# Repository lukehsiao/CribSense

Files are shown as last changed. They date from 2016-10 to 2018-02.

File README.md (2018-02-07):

# CribSense: <small>a contactless, video-based baby monitor</small>





# Documentation

Please view our [Documentation Pages](https://lukehsiao.github.io/CribSense) for details and instructions on how to build the project.

## Copyright & License

For license information, view our [license file](LICENSE.md).

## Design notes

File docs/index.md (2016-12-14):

# CribSense Overview

CribSense is a contactless, video-based baby monitor that you can make yourself without breaking the bank.

<a href="img/render-2.jpg">
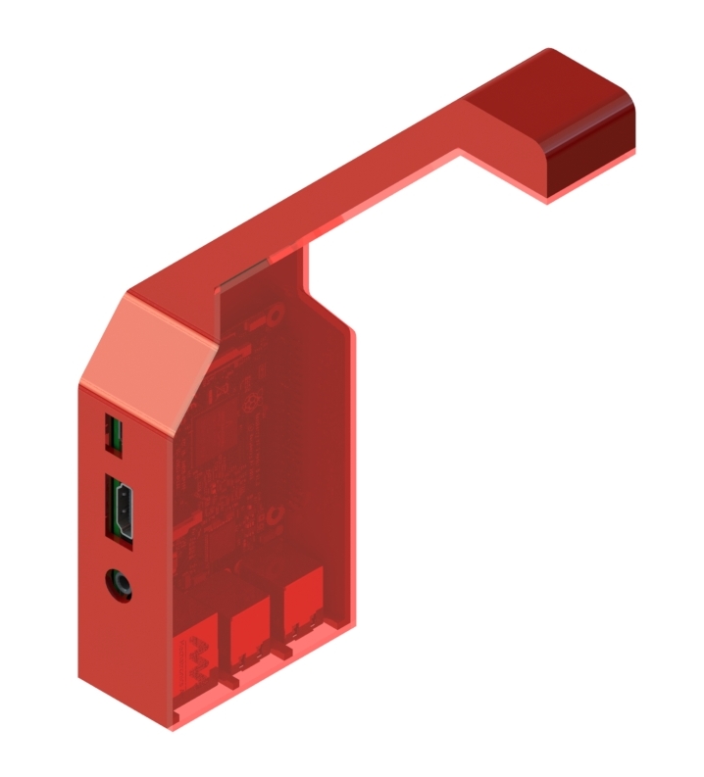
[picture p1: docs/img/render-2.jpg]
render
  
</a>
<a href="img/complete-standing.jpg">
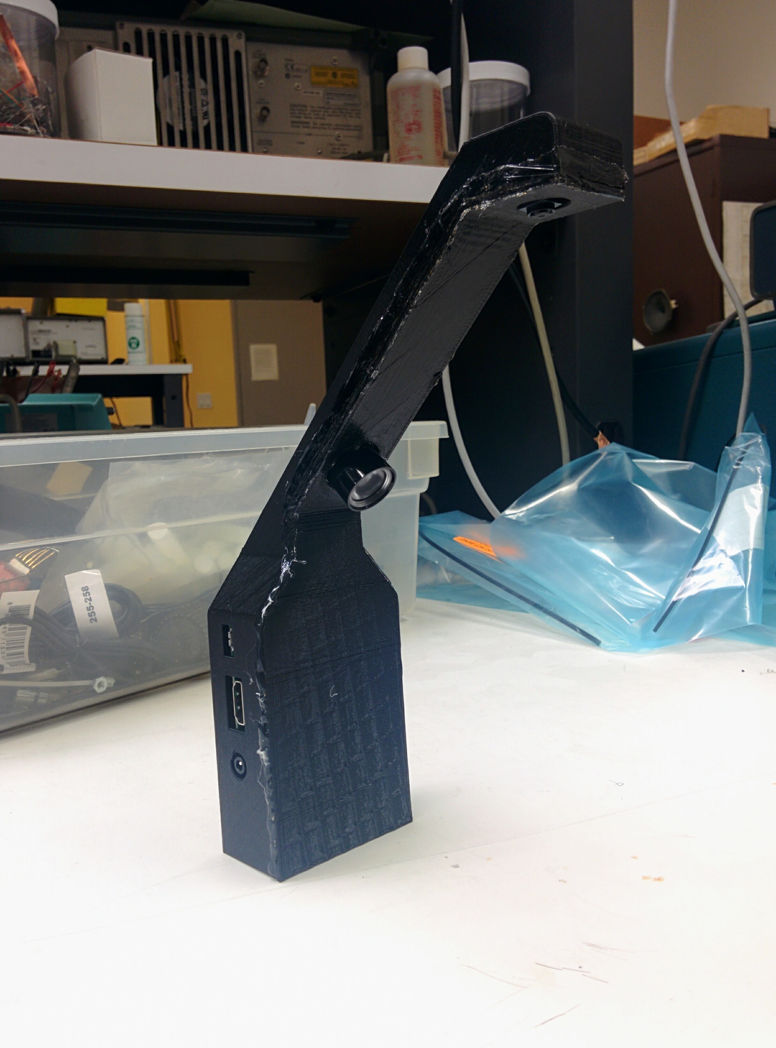
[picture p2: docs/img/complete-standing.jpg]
  
</a>

CribSense is a C++ implementation of the MIT [Video Magnification](http://people.csail.mit.edu/mrub/vidmag/) algorithm that is tuned to run on a Raspberry Pi 3 Model B.
Over a weekend, you can setup your own crib-side baby monitor that raises an alarm if your infant stops moving.
As a bonus, all of the software is free to use for non-commercial purposes and easily extensible.

While we think that CribSense is pretty fun, it is important to remember that this is not actually a certified, foolproof safety device.
That is, CribSense will not work as expected if the system is not calibrated properly.
If the system is not calibrated well or the environment in the video is not conducive to video magnification, you may not be able to use it.
We made this as a fun side project to see how well we could run compute-heavy software, like video magnification, on compute-limited hardware, like a Raspberry Pi.
Any real product would require much more testing than we have done.
If you use this project, take it for what it is: a short exploration of video magnification on a Raspberry Pi.

## Getting Started

CribSense is made up of two parts: the baby monitoring software and some simple hardware.
Find out all you need to know about how to use and recreate your own monitor in the sections below.
You can also view our instructions on [Instructables](http://www.instructables.com/id/CribSense-a-Contactless-Video-based-Baby-Monitor/).

### Software

To install the prerequisites, build the software, or learn more about the software architecture, see the [Software Setup Guide](setup/sw-setup.md).

### Hardware

To learn more about the hardware materials we used, and how we build our setup, check out the [Hardware Setup Guide](setup/hw-setup.md).

## Video Walkthroughs

### Calibrating CribSense

<iframe width="560" height="315" src="https://www.youtube.com/embed/zSiRmgIE3pY?rel=0" frameborder="0" allowfullscreen></iframe>

### CribSense Demonstration

<iframe width="560" height="315" src="https://www.youtube.com/embed/zvy1fXIjGgA?rel=0" frameborder="0" allowfullscreen></iframe>

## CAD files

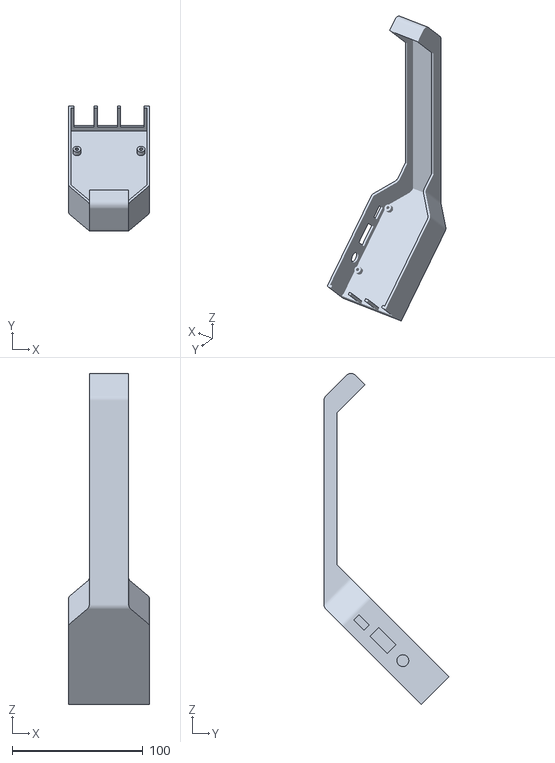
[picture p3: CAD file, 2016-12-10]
chassis/case.stl
62.0 x 95.5 x 252.8

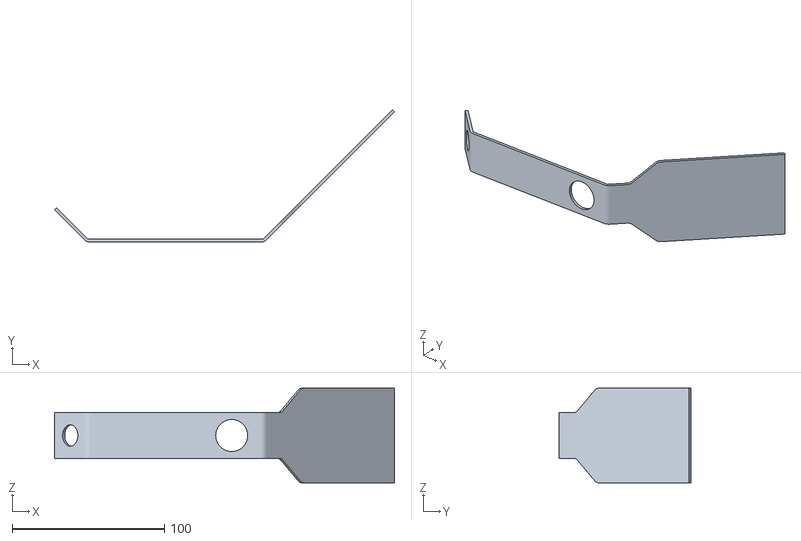
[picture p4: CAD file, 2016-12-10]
chassis/cover.stl
223.0 x 86.9 x 62.0

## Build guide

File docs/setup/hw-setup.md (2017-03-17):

# Hardare Setup Guide

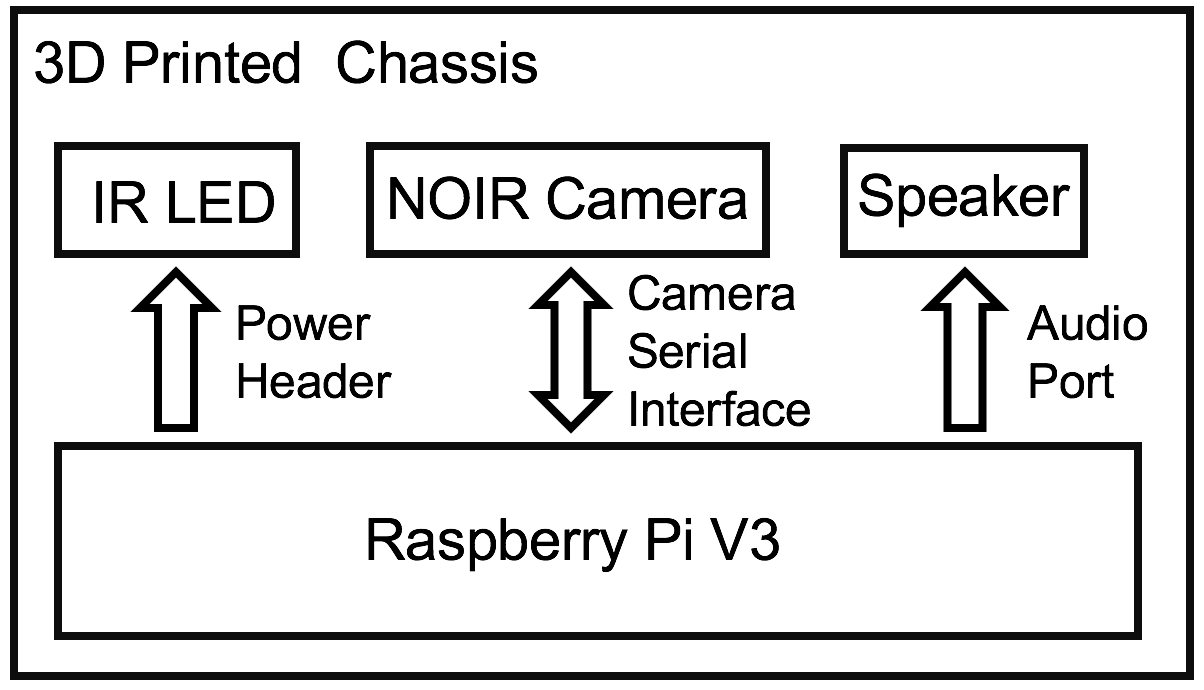
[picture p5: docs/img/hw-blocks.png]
hw-blocks


**Figure: Hardware Block Diagram**

CribSense is relatively easy to construct, and is largely made up of commercially available parts.
As seen in the figure above, there are 5 main hardware components, only 2 of which are custom made.
This page contains the build instructions for CribSense.

## What you'll need

Raspberry Pi + Camera + configuration tools:

-   [Raspberry Pi 3 Model B](https://www.amazon.com/Raspberry-Pi-RASP-PI-3-Model-Motherboard/dp/B01CD5VC92/)
-   [5V 2.5A Micro USB Power Supply](https://www.amazon.com/gp/product/B00MARDJZ4/)
-   [Raspberry Pi NoIR Camera Module V2](https://www.amazon.com/Raspberry-Pi-NoIR-Camera-Module/dp/B01ER2SMHY)
-   [1W IR LED](https://www.amazon.com/DIYmall%C2%AE-Infrared-Adjustable-Resistor-Raspberry/dp/B00NUOO1HQ)
-   [MicroSD Card](https://www.amazon.com/Samsung-Class-Adapter-MB-MP32DA-AM/dp/B00IVPU7KE) (we used a Class 10 16GB card, the faster the card the better)
-   [Flex Cable for Raspberry Pi Camera (12")](https://www.adafruit.com/products/1648)
-   Speakers with 3.5mm input
-   HDMI monitor
-   USB Keyboard
-   USB Mouse
-   \[optional] [Raspberry Pi Heatsink](https://www.amazon.com/LoveRPi-Heatsink-Raspberry-Model-Heatsinks/dp/B018BGRDVS/) (If you're worried about heat, you can stick these onto your Pi.)

IR LED Circuit for low-light operation:

-   [\[3x\] 1N4001 diodes](https://www.adafruit.com/product/755)
-   [1 ohm, 1W resistor](http://www.parts-express.com/10-ohm-1w-flameproof-resistor-10-pcs--003-1)
-   [2x] 12" Wires with pin headers
-   Soldering iron

Chassis:

-   Access to a 3D printer (minimum build volume = 9.9" L x 7.8" W x 5.9" H) to print the chassis
-   Glue (any type of glue will will work, but hot glue is recommended for prototyping)

## Prerequisites

Before you start our step-by-step guide, you should have already installed the latest version of [Raspbian](https://www.raspberrypi.org/downloads/raspbian/) on your SD card and ensured that your Pi is functional and booting.
You'll also need to [enable the camera module](https://www.raspberrypi.org/documentation/configuration/camera.md) before you'll be able to interface with the camera.

## Build Instructions

### Swap NoIR Camera Cable

The 6" cable that comes with the camera is too short.
Swap the short one (6") with the longer one (12").
To do this, you can follow [this guide from ModMyPi](https://www.modmypi.com/blog/how-to-replace-the-raspberry-pi-camera-cable).
To summarize, there is a push/pull tab on the back of the NoIR camera, just like the one found on the Pi itself:

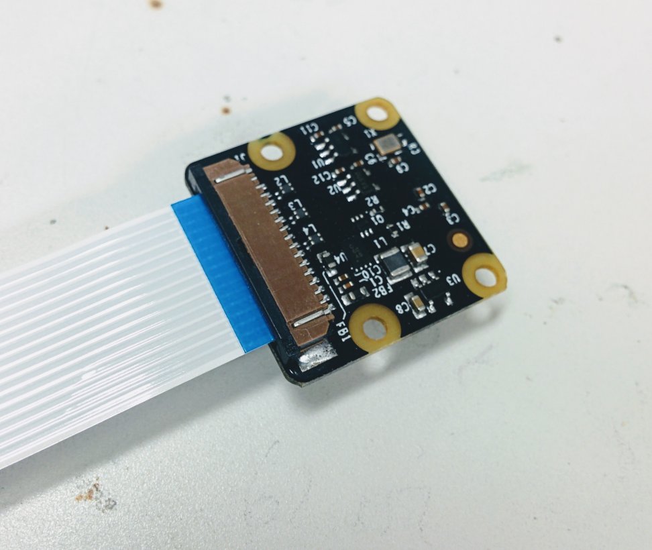
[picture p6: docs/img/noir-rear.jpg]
noir-rear


Simply pull the black plastic tab out, remove the short cable, replace it with the long cable (making sure that the blue plastic strip is facing up still as shown in the picture), and push the tab back in to secure it.

### 3D Printed Chassis

<a href="../../img/render-2.jpg">
  Render 2
</a>

Using our chassis is optional, though recommended to prevent young children from touching exposed electronic circuitry.
Every crib is different, so our chassis does not include include a mounting bracket.
Several mounting options could include:

-   [Cable Ties](https://www.amazon.com/Miady-Pieces-Self-Locking-Nylon-Inches/dp/B01M0IL0GO/)
-   [3M Dual Lock](https://www.amazon.com/3M-Reclosable-Fastener-SJ3560-Clear/dp/B00PX22H42/)
-   [Velcro](https://www.amazon.com/VELCRO-Brand-Industrial-Strength-Black/dp/B00006RSP1/)
-   Tape

If you have access to a MakerBot Replicator (5th Generation), you can simply download the `.makerbot` files for the [case](https://github.com/lukehsiao/CribSense/raw/master/chassis/case.makerbot) and [cover](https://github.com/lukehsiao/CribSense/raw/master/chassis/cover.makerbot) onto your MakerBot Replicator and print.
It takes about 6 hours to print the case and 3 hours to print the cover.
If you are using a different type of 3D printer, please keep reading.

As mentioned above, a minimum build volume of 9.9" (L) x 7.8" (W) x 5.9" (H) is required to print CribSense.
If you do not have access to a 3D printer with this build volume, you can use an online 3D printing service (such as [Shapeways](http://www.shapeways.com/) or [Sculpteo](https://www.sculpteo.com/)) to print CribSense.
The minimum print resolution is 0.015".
If you are using a [fused filament fabrication](https://en.wikipedia.org/wiki/Fused_filament_fabrication) type 3D printer, this means that your nozzle diameter needs to be 0.015" or smaller.
Printers with lower print resolutions (larger nozzle diameters) may work, but the Raspberry Pi might not fit into the chassis.
We recommend PLA (polylactic acid) as the preferred printing material.
Other plastics may work, but the Raspberry Pi may not fit in the case if the thermal expansion coefficient of the chosen plastic is larger than that of PLA.
If your 3D printer has a heated build plate, turn off the heater before proceeding.

Orienting the model on your printer's build plate is critical for a successful print.
These models were carefully designed so they do not need to be printed with support material, thus saving plastic and improving print quality.
Before proceeding, download the 3D files for the [case](https://github.com/lukehsiao/CribSense/blob/master/chassis/case.stl) and [cover](https://github.com/lukehsiao/CribSense/blob/master/chassis/cover.stl).
When printing these models, the neck of CribSense must lay flat on the build plate.
This ensures that all overhang angles on the models do not exceed 45 degrees, thus eliminating the requirement for support material.
For instructions on orientating 3D models in the build volume of your printer, please refer to the instruction manual that comes with your 3D printer.
Examples for the build orientation of the case and cover are shown below.

Case:

<a href="../../img/print-case-iso.png">
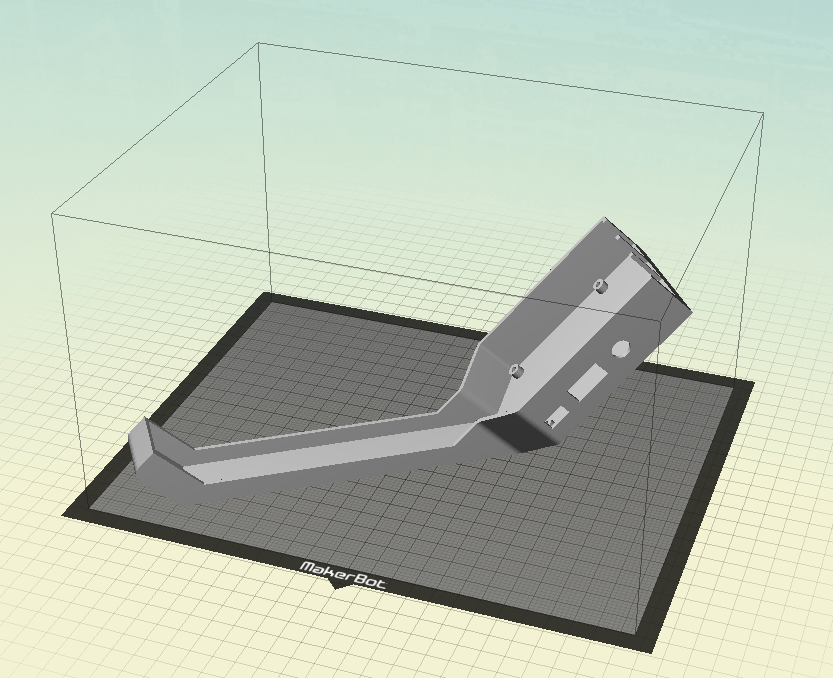
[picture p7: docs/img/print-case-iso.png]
Case (Isometric View)
  
</a>
<a href="../../img/print-case-top.png">
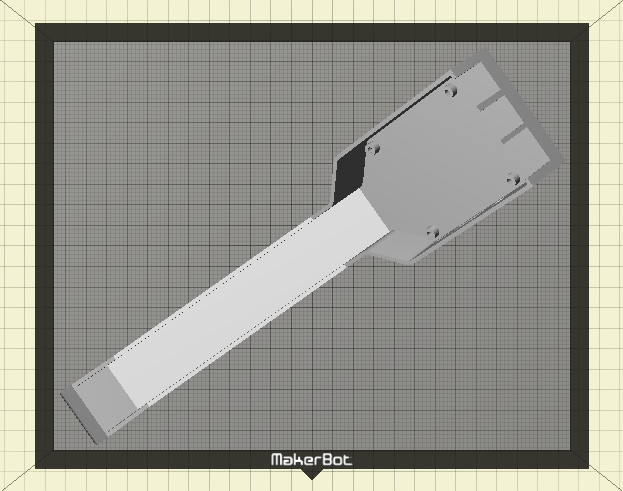
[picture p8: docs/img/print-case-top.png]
Case (Top View)
  
</a>

Cover:

<a href="../../img/print-cover-iso.png">
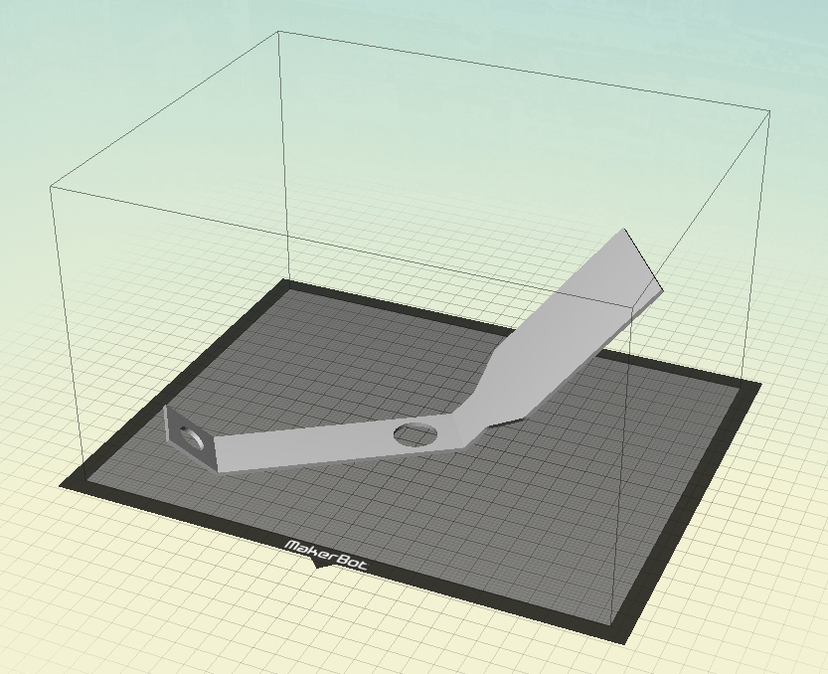
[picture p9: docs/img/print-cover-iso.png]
Cover (Isometric View)
  
</a>
<a href="../../img/print-cover-top.png">
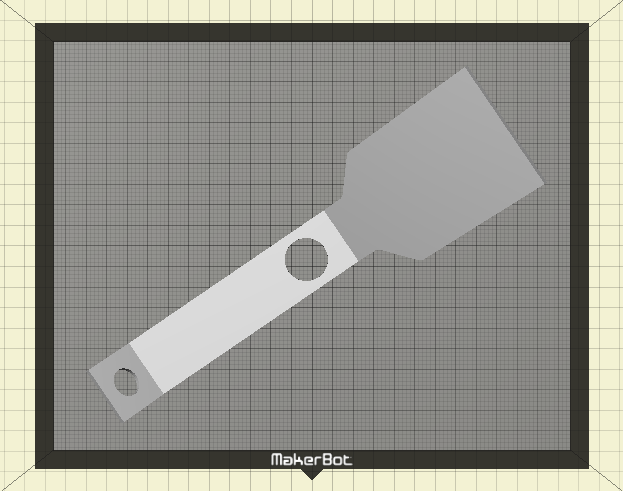
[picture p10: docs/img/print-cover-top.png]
Cover (Top View)
  
</a>

In addition to putting the neck of CribSense flat against the build plate, you may notice that the models are rotated around the vertical axis.
This may be necessary to fit the model inside the build volume of your 3D printer.
This rotation is optional if the length of your build volume is long enough to accommodate CribSense.

### IR LED Circuit

In order to provide adequate lighting at night, we use an IR LED, which is not visible to the human eye but visible to the NoIR camera.
The IR LED does not consume a lot of power compared to the Raspberry Pi, so we leave the IR LED on for the sake of simplicity.

To power the LED from the GPIO header pins on the Pi, we construct the circuit in the figure below.

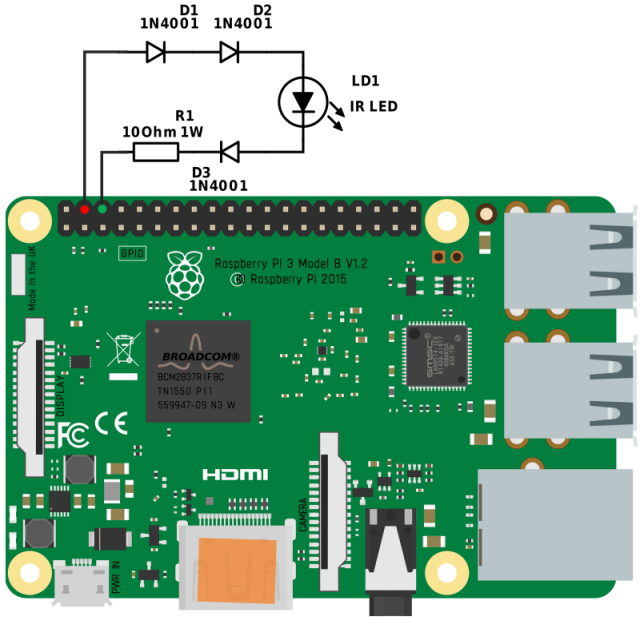
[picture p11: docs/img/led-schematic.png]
led

**Figure: LED Schematic**

In earlier versions of the Pi, the maximum output current of these pins was [50mA](http://pinout.xyz/pinout/pin1_3v3_power).
The Raspberry Pi B+ increased this to 500mA.
However, for simplicity and backwards compatibility, we use the 5V power pins, which can supply up to [1.5A](http://pinout.xyz/pinout/pin2_5v_power).
The forward voltage of the IR LED is about 1.7~1.9V according to our measurements.
Even though the IR LED has a maximum current of 500mA, we decided to reduce the current to around 200mA to reduce heat and overall power consumption.
Experimental results also show that the IR LED is bright enough with 200 mA of input current.
To bridge the gap between 5V and 1.9V, we decided to use three 1N4001 diodes and a 1 Ohm resistor in series with the IR LED.
The voltage drop over the wire, diodes and resistor is about 0.2V, 0.9V (for each one) and 0.2V, respectively.
Thus, the voltage over the IR LED is `5V - 0.2V - (3 * 0.9V) - 0.2V = 1.9V`.
The heat dissipation over each LED is 0.18W, and is 0.2W over the resistor, all well within the maximum ratings.

The circuit should looking something like this:

<a href="../../img/ir-led-zoom.jpg">
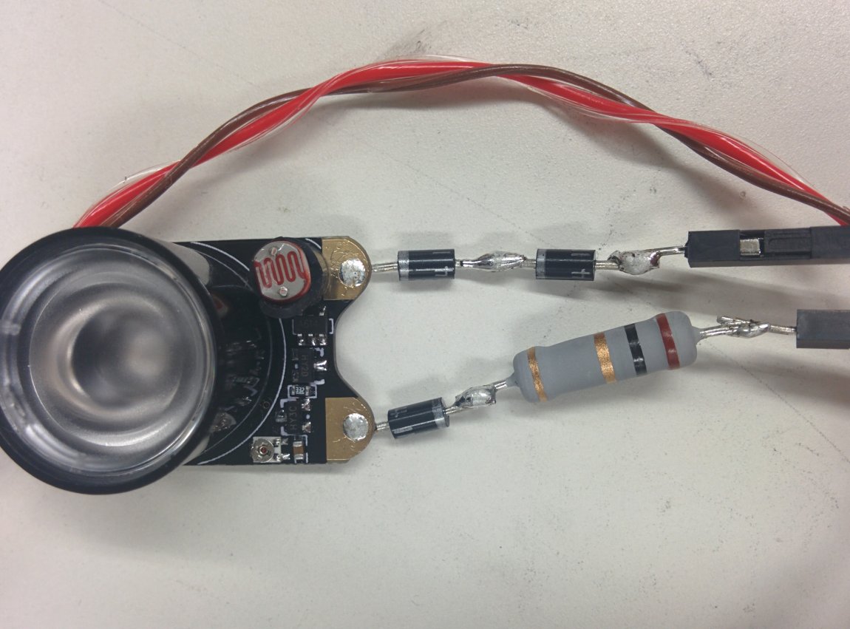
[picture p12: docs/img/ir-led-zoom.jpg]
zoom
  
</a>
<a href="../../img/ir-led-full.jpg">
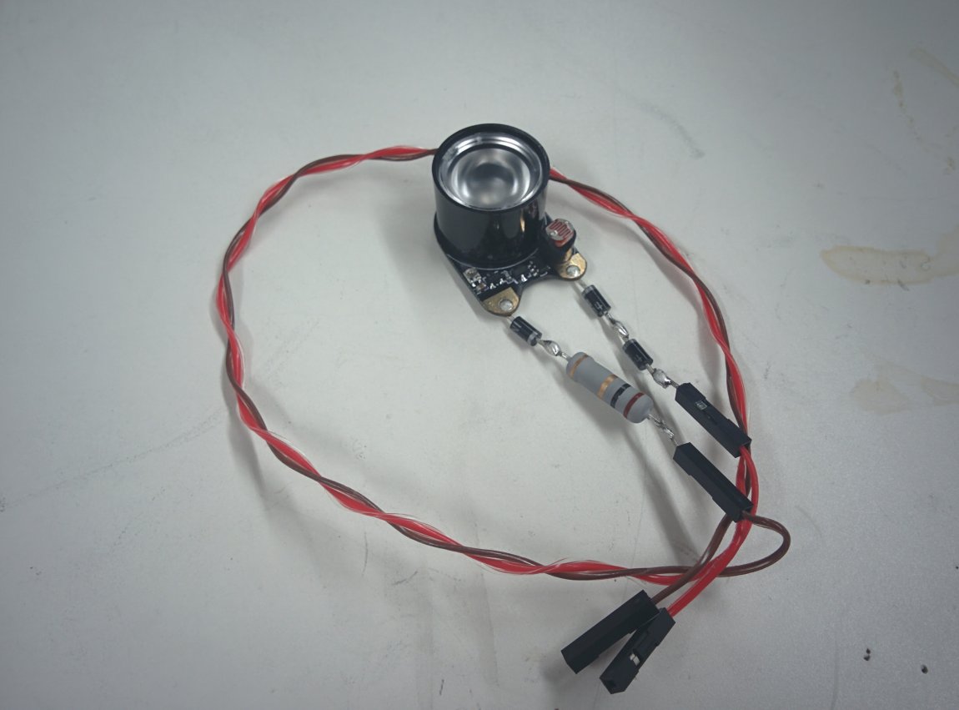
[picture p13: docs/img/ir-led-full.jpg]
full
  
</a>

But, we're not done yet!
In order to get a better fit in the 3D printed chassis, we want to have the IR LED lens protrude from our chassis and have the PCB board flush with the hole.
The small photodiode in the bottom right will get in the way.
To remedy this, we desolder it and flip it to the opposite side of the board like this:

<a href="../../img/photodiode-side.jpg">
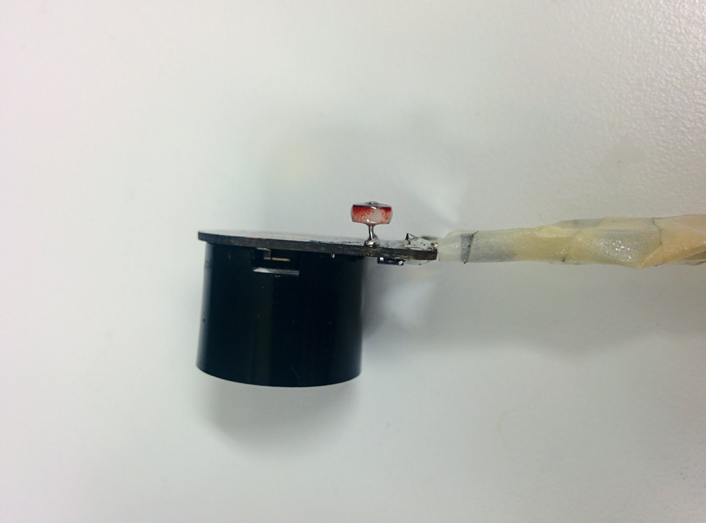
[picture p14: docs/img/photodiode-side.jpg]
side
  
</a>
<a href="../../img/photodiode-front.jpg">
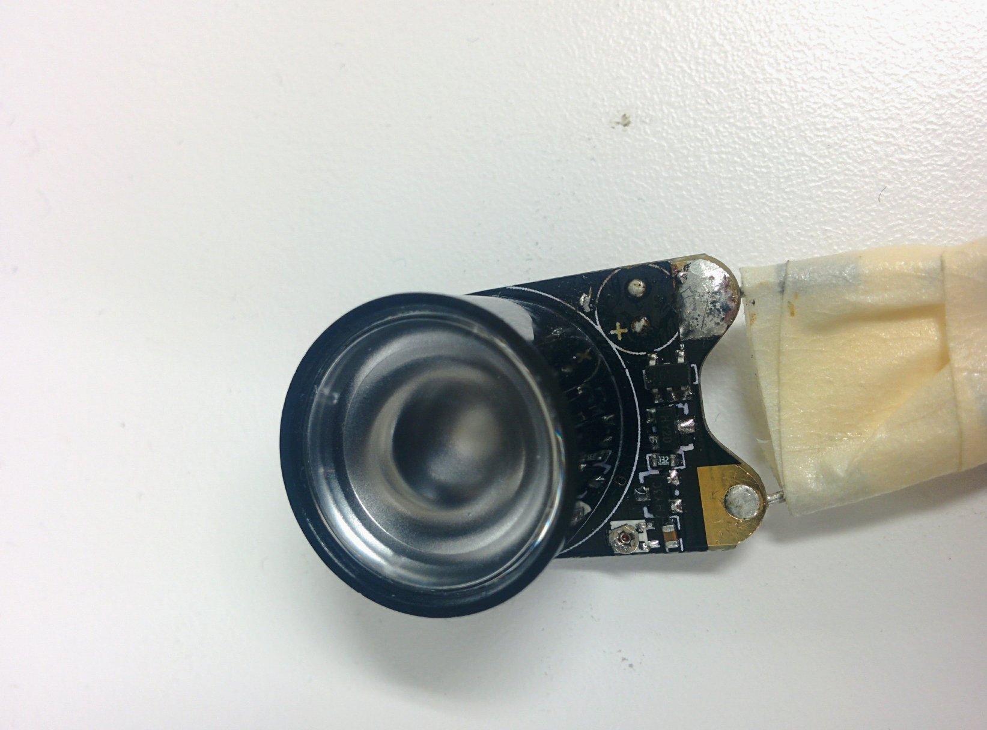
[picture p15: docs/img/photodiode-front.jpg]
front
  
</a>

The photodiode is not needed since we want the LED to always be on.
Simply switching it to the opposite side leaves the original LED circuit unchanged.

### Assembly: Bring it all together

Once you have all the hardware ready, you can begin assembly.
Any glue can be used in this process, but we recommend hot glue for two main reasons.
Hot glue drys quickly, so you do not need to wait a long time for the glue to dry.
In addition, hot glue is removable if you make a mistake.
To remove dried hot glue, soak the hot glue in in rubbing (isopropyl) alcohol.
We recommend 90% concentration or higher, but 70% concentration will still work.
Soaking the dried hot glue in isopropyl alcohol will weaken the bond between the glue and underlying surface, allowing you to peel the glue off cleanly.
When soaking the glue in isopropyl alcohol, the Raspberry Pi should be powered off and unplugged.
Be sure to let everything dry before reapplying hot glue and booting the Raspberry Pi.

The assembly instructions below assume that you are using hot glue.
If you are using a different type of glue, the assembly instructions still apply, though the drying times may differ.
Throughout this process, make sure that the glue is dry before moving on to the next step.
Throughout the build, check to make sure that all the ports can still be accessed through the holes in the CribSense chassis.
Click any of the pictures below for higher resolution images.

-   Insert the Raspberry Pi into the chassis. Once it is in place, be sure that all of the ports can still be accessed (e.g. you can plug in power power).

<a href="../../img/pi-chassis.jpg">
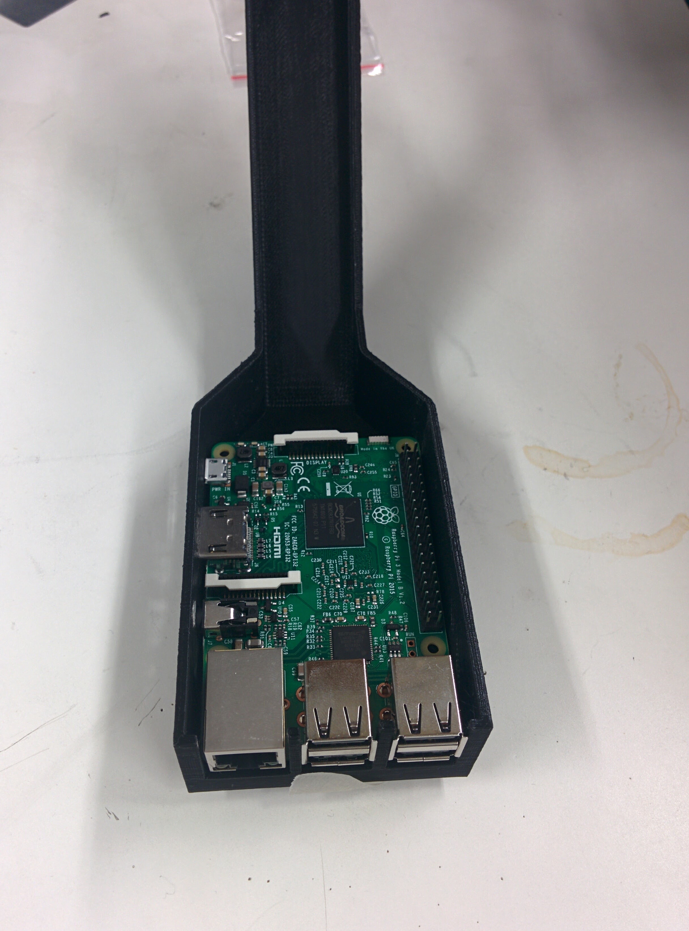
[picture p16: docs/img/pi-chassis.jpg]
  
</a>

-   Next, use hot glue to tack the Pi into place and attach the camera to the Pi. There are screw holes as well if you prefer to use those.

<a href="../../img/pi-glued.jpg">
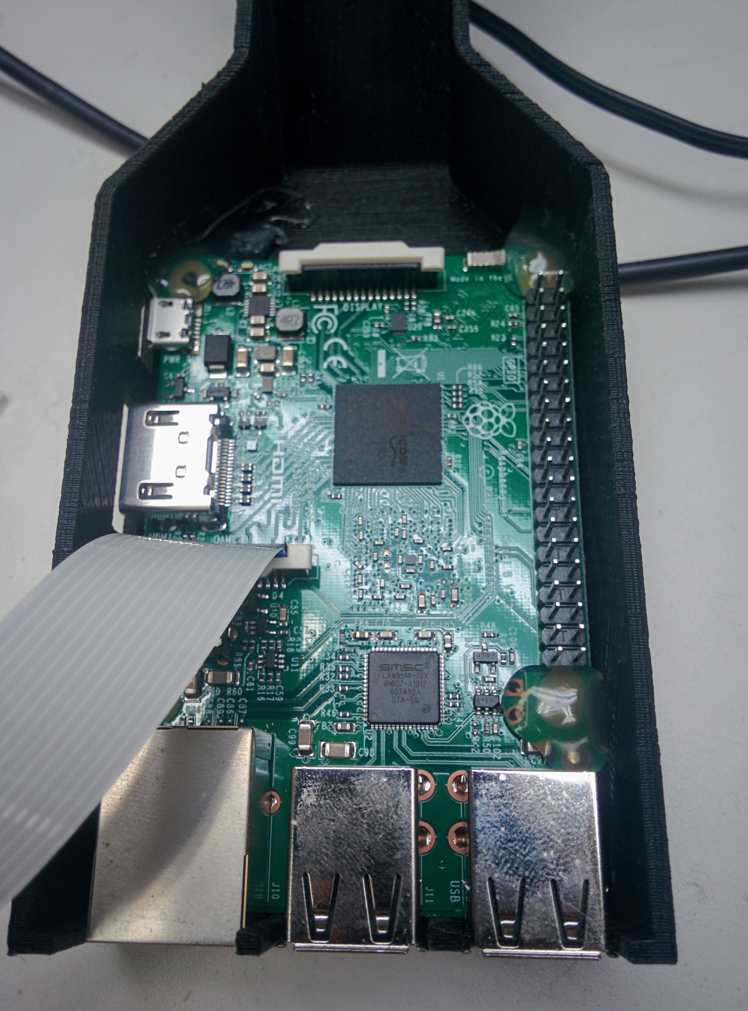
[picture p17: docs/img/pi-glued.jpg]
  
</a>

-   Glue the LED and camera to the front cover.

<a href="../../img/chassis-front.jpg">
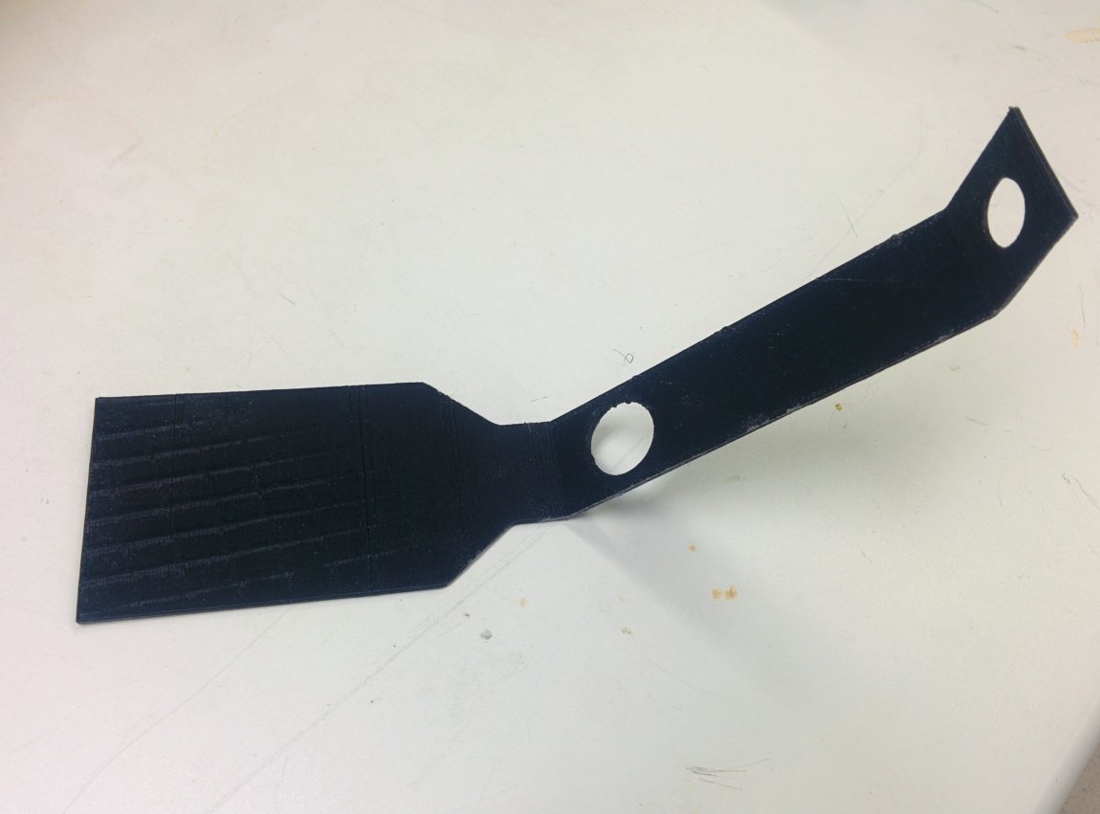
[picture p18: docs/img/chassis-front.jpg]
front
  
</a>

-   First, glue the NoIR camera to the camera hole. Be sure that the camera is snug and lined up with the chassis. Do not use too much glue; otherwise, you will not be able to fit the camera into the main case. Be sure to power on the Pi and take a look at the camera (`raspistill -v`, for example) to make sure that it is angled well and has a good field of view. If it is not, remove the hot glue and reposition it.

<a href="../../img/noir-glued.jpg">
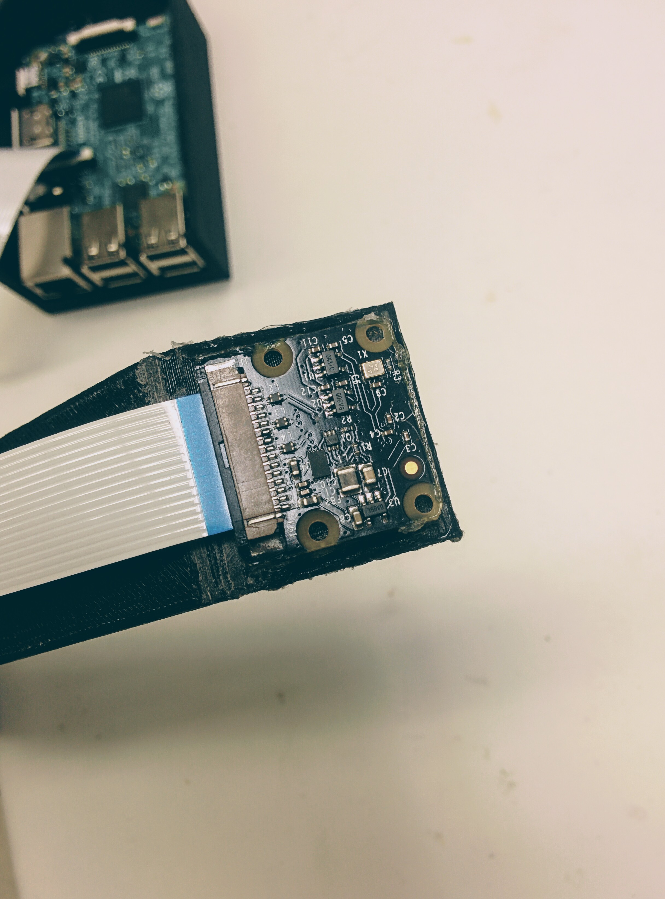
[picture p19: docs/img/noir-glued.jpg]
  
</a>

-   Next, glue the IR LED to the hole on the neck of the cover. It's at a 45 degree angle to side light the crib, which results in more shadows in low-light situations. This adds more contrast to the image, making it easier to detect motion.

<a href="../../img/ir-led-glued-zoom.jpg">
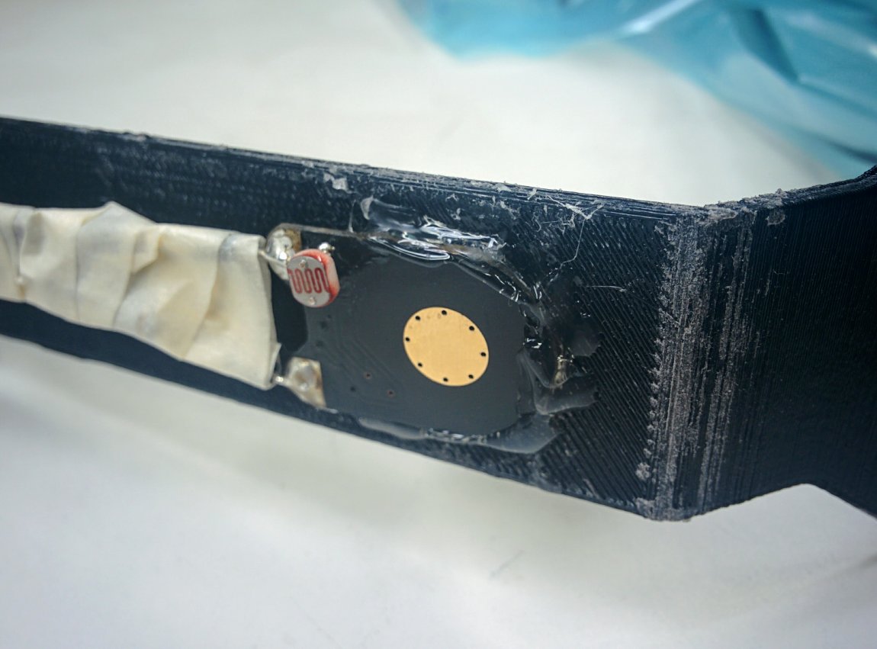
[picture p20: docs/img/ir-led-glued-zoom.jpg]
  
</a>

-   With both of them glued to the neck, it should look like this:

<a href="../../img/ir-led-glued-front.jpg">
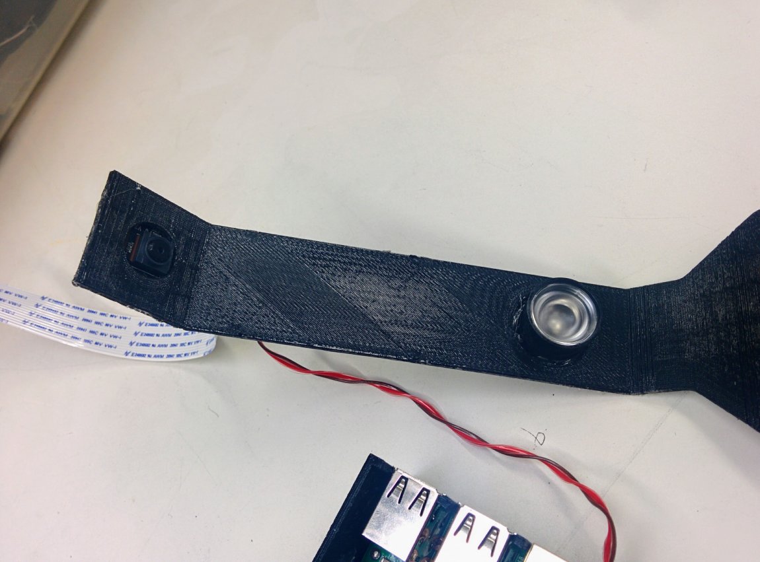
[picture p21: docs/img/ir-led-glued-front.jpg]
front
  
</a>
<a href="../../img/ir-led-glued-rear.jpg">
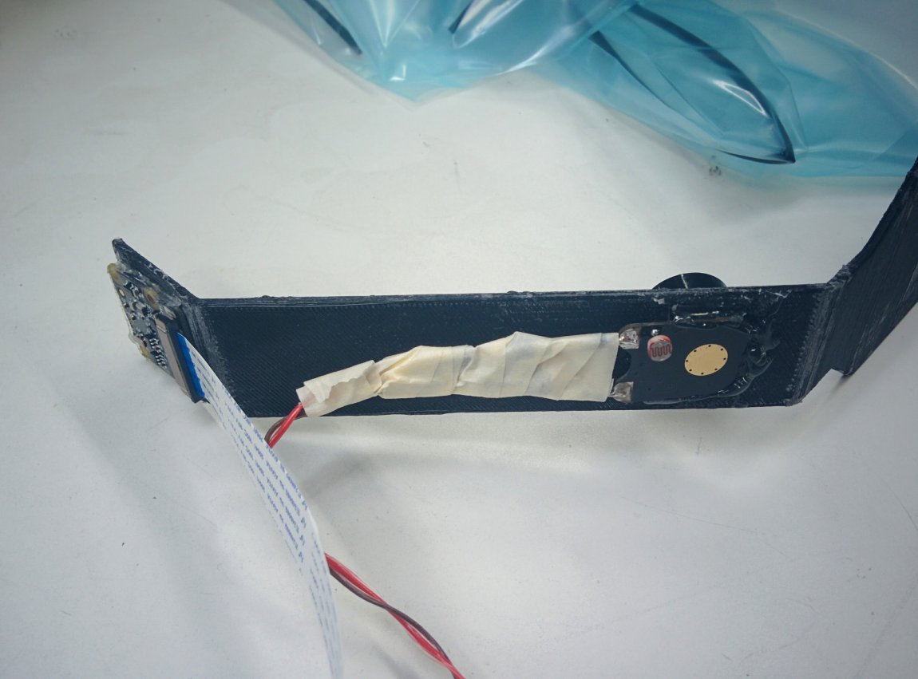
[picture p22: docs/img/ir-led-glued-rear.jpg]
  
</a>

-   Attach the IR LED wires to the Raspberry Pi's GPIO pins as shown in the LED Schematic figure.
-   Pack the cables into the chassis in a way that does not crease or strain them. We ended up folding the cable accordion style because our camera flex cable was too long.

<a href="../../img/cable-packing.jpg">
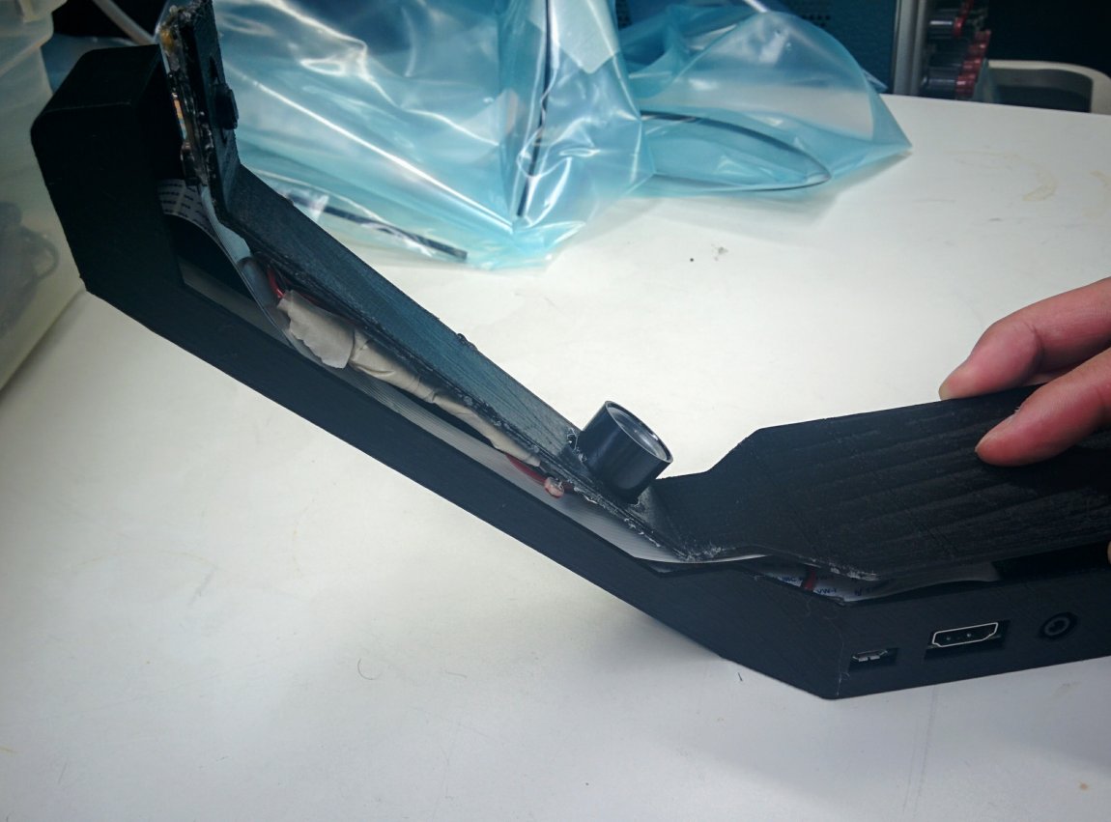
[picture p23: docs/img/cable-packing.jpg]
  
</a>

-   With everything tucked in, hot glue around the edges where the two pieces meet, sealing them in place.

<a href="../../img/complete-standing.jpg">
  front
</a>
<a href="../../img/complete-ports.jpg">
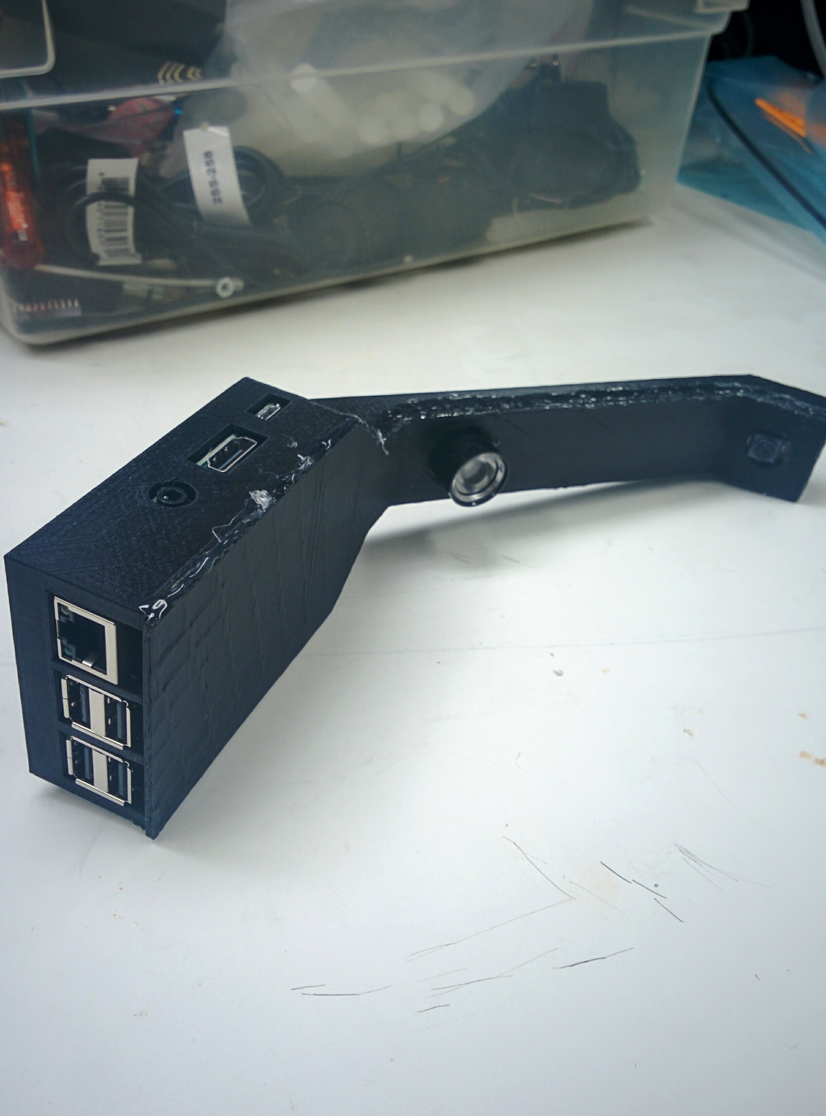
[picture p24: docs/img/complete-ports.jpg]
  
</a>

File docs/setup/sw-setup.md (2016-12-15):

# Software Setup Guide

This is the step-by-step guide on building the CribSense software on Raspbian/Ubuntu.

## Prerequisites

This software depends on [autoconf](https://www.gnu.org/software/autoconf/autoconf.html), [libtool](https://www.gnu.org/software/libtool/), [OpenCV](http://opencv.org/) and [libcanberra](https://en.wikipedia.org/wiki/Libcanberra). Install these by running

```sh
sudo apt-get install git build-essential libtool autoconf libopencv-dev libcanberra-dev
```

Next you need to set to camera driver to autoload by adding `bcm2835-v4l2` to `/etc/modules-load.d/modules.conf`.
Your `modules.conf` should look like this:

```sh
# /etc/modules: kernel modules to load at boot time.
#
# This file contains the names of kernel modules that should be loaded
# at boot time, one per line. Lines beginning with "#" are ignored.

i2c-dev
bcm2835-v4l2
```
Once you've added the line and saved the file, **reboot your Raspberry Pi**.
This is the driver used by CribSense to directly pull frames from the NoIR Camera.

## Build

To build the software, navigate to the root of the repository directory and run

```sh
./autogen.sh --prefix=/usr --sysconfdir=/etc --disable-debug
make
sudo make install
sudo systemctl daemon-reload
```
## Usage

To start the program in the background:

```sh
sudo systemctl start cribsense
```

To run it in the foreground:

```sh
cribsense --config /etc/cribsense/config.ini
```

To start the program automatically at every boot:

```sh
sudo systemctl enable cribsense
```

To stop cribsense from automatically running at boot:

```sh
sudo systemctl disable cribsense
```

Note that when `cribsense` is started using `systemctl`, the config parameters are already sent and are stored in `/etc/systemd/system/cribsense.service`

Once you have installed the software and have it configured well for your setting, you will no longer need the keyboard/mouse/monitor. Now, you can set your CribSense to autorun at every boot as shown above.

Now, all you'll need to do is plug in speakers, attach the CribSense to your previously tested spot on the side of your crib, and plug it in. The software will automatically run after a few moments, and will begin tracking motion. When you're done, well, we don't have an elegant way for you to turn off the Pi yet. But, you can just unplug the speakers and leave it running (and be sure to set the infant in the crib for a couple minutes before plugging them back in). Directly unplugging the Pi may corrupt your SD card.

Remember that if the environment changes, you'll probably need to reconfigure. You'll want to disable the autorun using the command above, and go through the calibration steps on the [Configuration Page](./config.md).

If something doesn't seem to be working, you can checkout our [Troubleshooting Page](./troubleshooting.md)

Tip: If everything is set up, you can [make a backup of your Raspberry Pi SD Card](https://www.raspberrypi.org/documentation/linux/filesystem/backup.md) for easy restoration if something goes wrong.

## Software Configuration

CribSense customizable through a simple INI configuration file.
After running `make install`, the configuration file is located at:

```sh
sudo nano /etc/cribsense/config.ini
```

and it will look like this
```ini
[io]                  ; I/O configuration
; input = vid/noir_cam/lowres_10fps_orange_2min.h264   ; Input file to use
input_fps = 15          ; fps of input (40 max, 15 recommended if using camera)
full_fps = 4.5          ; fps at which full frames can be processed
crop_fps = 15           ; fps at which cropped frames can be processed
camera = 0              ; Camera to use
width = 640             ; Width of the input video
height = 480            ; Height of the input video
time_to_alarm = 10      ; How many seconds to wait with no motion before alarm.

[cropping]            ; Adaptive Cropping Settings
crop = true                 ; Whether or not to crop
frames_to_settle = 10       ; # frames to wait after reset before processing
roi_update_interval = 800   ; # frames between recalculating ROI
roi_window = 50             ; # frames to monitor before selecting ROI

[motion]              ; Motion Detection Settings
erode_dim = 4           ; dimension of the erode kernel
dilate_dim = 60         ; dimension of the dilate kernel
diff_threshold = 8      ; abs difference needed before recognizing change
duration = 1            ; # frames to maintain motion before flagging true
pixel_threshold = 5     ; # pixels that must be different to flag as motion
show_diff = false       ; display the diff between 3 frames

[magnification]       ; Video Magnification Settings
amplify = 25                ; The % amplification desired
low-cutoff = 0.5            ; The low frequency of the bandpass.
high-cutoff = 1.0           ; The high frequency of the bandpass.
threshold = 50              ; The phase threshold as % of pi.
show_magnification = false  ; Show the output frames of each magnification

[debug]
print_times = false ; Print analysis times

```

View the full configuration details on the [Configuration Page](./config.md)

## Software Architecture Details
The CribSense software is the heart and soul of this project.
The rest is mainly a fun opportunity to use a 3D printer and do some soldering.
We saw some of the great demos of [video magnification](http://people.csail.mit.edu/mrub/vidmag/) from MIT, and wanted to try and run a similar algorithm on a Raspberry Pi.
 This required about 10x speedup from the great work of [tbl3rd on his C++ implementation](https://github.com/tbl3rd/Pyramids) of video magnification in order to run in real-time on the Pi.
 The optimizations needed guided our design of the software.

The software for processing a video stream is implemented as a state machine that cycles as shown below.
There are currently six states that manage all of our processing steps.
Our state machine logic is called each time a new frame is read from the camera.

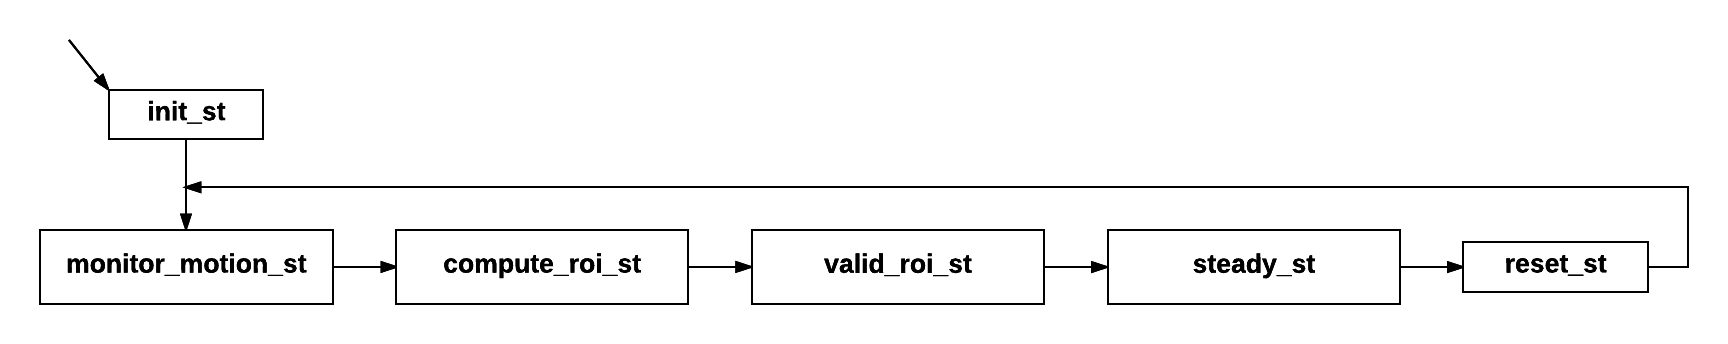
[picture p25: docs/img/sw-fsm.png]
fsm


### Initialization

When the video stream first turns on, it is common to have a flash of white or black pixels that looks like a lot of motion is happening.
This state simply initializes the video magnification and motion detection code, and skips a few of the first frames before jumping into monitoring motion.

### Monitoring Motion

In this state, the full 640 x 480 frame is magnified, and uses an image differential algorithm from Collins et al. to calculate the motion pixels between frames.
The output of this algorithm is a black and white image where white pixels indicate pixels that have changed.
These black and white images are then bitwise ORed together for several frames to accumulate the motion seen over the period of time.

### Computing a Region of Interest

With the accumulated black and white frame representing the motion seen over several frames, the image is eroded slightly to eliminate noise, then significantly dilated to highlight the areas with the most motion.
Dilation is necessary to merge discrete points into continuous regions of motion.
Because of the large dilation, it is then easy to find the largest contour in the black and white image, which represents the main source of motion, and draw a bounding box around the contour.
It is in this portion of code that we can set bounds on the size of the crop.

### Steady State

This is where our software spends most of its time.
In this state, the software is operating on cropped frames.
Video magnification is performed and a measure of the movement seen in the frame is calculated.
In this state, we are able to process at a fast enough rate to catch up with any delay caused during the processing of full frames, and keep up with our 10fps video stream.

### Periodic Reset

Because the baby may move occasionally, we periodically reset the video magnification and cropping so that we have full-resolution frames available to repeat the process of monitoring motion and finding a new region of interest.
All of these timing parameters are easily configurable.

## Technical Challenges

### Speed

When we started this project, our C++ implementation could magnify video at a rate of 394,000 pixels per second on the Raspberry Pi 3.
For reference, this meant our code could only process a 640 x 480 video stream at a rate of approximately 1.3 frames per second.  
Optimizing our code to handle the real-time goal was our primary objective and challenge, since we needed a 10x speed-up to handle at least 10 frames per second.
Now, we are able to process over 1,200,000 pixels per second, and use additional cropping to process a 10 fps video stream in real time.

We used three main optimizations increase performance by 10x: (1) multithreading, (2) adaptive cropping, and (3) compiler optimization. Each optimization is explained in more detail below.

#### Multithreading (~3x)

One intuitive and high-value optimization was to process sections of each video frame in parallel.
To do so, we divide each frame vertically, such that each section's height is one-third of the original frame.
Then, each section is magnified as if it was its own video stream.
The resulting magnified frames are then joined together to form a full-resolution frame before evaluating the frame for motion.
This optimization alone brought our processing rate to 938,000 pixels per second (roughly a 3x improvement).
Three of the Raspberry Pi's four cores are dedicated to video magnification, while the 4th core handles control flow and motion processing.

#### Adaptive Cropping (~3x)

While multithreading sought to increase the number of pixels we could process each second, adaptive cropping sought to decrease the number of pixels we needed to process.
We rely on two main assumptions for this optimization.
First, the camera captures the entire crib in its field of view and the baby is the only source of movement in the frame.
Second, the camera is placed such that movement is discernible, and the region of interest is not larger than one-third of the frame.
With these assumptions, we are able to periodically monitor a full frame to determine where the motion is occurring, then crop down the stream to only contain the relevant motion.
By reducing the number of pixels that we process in our steady state, and amortizing the cost of monitoring a few full-resolution frames, we are able to increase the number of frames we can handle each second by about 3x.

#### Compiler Optimizations (~1.2x)

Finally, in order to reach our goal of over 10x speedup, we were able to make some code optimizations and utilize additional compiler flags.
In particular, we make use of the -O3 optimization level, and we force the compiler to generate vector instructions with `-ftree-vectorize` and `-mfpu=crypto-neon-fp-armv8`.
Additionally, we were required to add the `-funsafe-math-optimization` flag to enable the vector float generation, because NEON instructions are not IEEE compliant and gcc would not generate them otherwise.

We found two major challenges in enabling compiler optimization.
The first was to expose the operations to the compiler.
The most expensive part of transformation happens in two all-pixel loops, but previously each operation in the loop was implemented with an opencv call that would run the operation over all pixels.
We rewrote the code to pull out the loop and avoid intermediate copies.
On an x86-64 machine, this is already an improvement, because of larger caches and the fact that the compiler always issues at least SSE2 vector instructions.
In contrast, the switch from vector instruction enabled opencv to straight C++ code resulted in worse performance on the Pi.

We recovered this performance drop by adding the compiler flags, but we encountered toolchain problems.
The Pi 3 has an ARM Cortex A53 processor, which is an A-class 64-bit ARMv8 with NEON and crypto extensions, but it runs a 32-bit OS compiled for ARMv7.
We found first that compiling with `-march=native` exposes a known but yet unfixed GCC bug.
Compiling with `-march=armv8` appears to work, but generates ABI incompatible binaries when linked with an ARMv7 libstdc++, leading to stack corruption.
On the other hand, leaving the default of -march=armv7 and forcing just the FPU to generate NEON appears to work, looking at the assembly.
We also added `-mtune=cortex-a53` to achieve better instruction scheduling and better counts for loop unrolling (which is enabled at -O3), but we suspect it has no effect because the version of GCC we use (4.9.2, provided by Raspbian) does not recognize it.

### Profiling

In order to isolate further optimization spots, we employed profiling to identify where the code is spending most of the time.
In doing so, we also encountered toolchain problems, as `valgrind` is unable to emulate the NEON vector instructions and crashes.
We therefore turned to `gprof`, but we found its timing somewhat unreliable, despite the `-fno-inline` switch (function call counts on the other hand are precise but not quite useful).
Finally, we tried `perf`, which uses the HW performance counters and gives us instruction level timings, but we found that it is very precise inside the transformation code, and has zero data outside, because it sees no sample of the other code.
Overall, profiling suggests that 96% of the time is spent in the transformation and 2% in motion detection, with the rest being threading and locking overhead, and accessing the camera.

### Timing

Overall, our algorithm is able to process a full 640x480 frame in 220 to 240 ms, while after cropping our algorithm runs in the worst case (where the crop is approximately 320x320) at about 70 ms per frame.
This allows us to maintain a steady 10 fps goal.

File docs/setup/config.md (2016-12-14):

# Configuration

Configuration of CribSense uses a file which is usually located in `/etc/cribsense/config.ini`.

The format is that of INI files: each line is a configuration value, and directives are grouped in section introduced by square brackets. Comments are delimited with `;` to the end of the line.

## Input/Output

The `[io]` section of the file configures the input to CribSense.
You should not need to modify this section, as it is already calibrated to work on the Raspberry Pi.

The `input` directive specifies that the magnifier should look for a video file instead of real-time camera input, while `camera` directive chooses the camera device to use (eg. `camera = 0` means to use `/dev/video0` as input).
File input exists as a demo or debugging feature only.

If you change the input, you must also specify the fps parameters to match the input.
For file input, there is only one fps setting, because frames are never dropped, while for camera input, to reduce latency you must specify the frame per second at full frame size and at cropped frame size (roughly 3x the full frame size fps).
The latter values depend on the speed of the CPU on which cribsense run.
Note that when using an input file that is less than 15 fps, `crop_fps` should be set to the input file's fps value in order to ensure the bandpass frequencies are calculated correctly.

`time_to_alarm` determines the number of system-time seconds to wait after cribsense stops seeing motion before playing an alarm sound through the audio port.

## Cropping

The `[cropping]` section controls the adaptive motion-based cropping, which focuses the magnification process on a smaller Region of Interest (ROI) where the most motion is occurring, reducing the CPU load.

The different parameters affect the latency of detection, as they control the number of "slow" frames (fully uncropped).
Optimal values for the parameters depend on the target CPU.
If you're running on a different device than the Pi, and it's sufficiently powerful, you can also disable cropping altogether.

The default configuration will update the crop approximately every minute.

## Motion & Magnification

The `[motion]` and `[magnification]` sections control the motion detection and video magnification algorithm respectively.

These parameters depend on the setting in which the cribsense is deployed, such as lighting condition and contrast on the baby.
In general, you should not need to change the magnification setting, as it is tuned to detect normal breathing rates.

Calibration may be needed for `erode_dim` and `dilate_dim`, which are used to determine where to crop the video, as well as `diff_threshold` and `pixel_threshold` which determine the thresholds used judge the magnitude of change in pixels and the number of pixels of motion are needed before being classified as motion rather than noise.

Specifically, `diff_threshold` specifies the amount of change a grayscale pixel (value between 0 and 255) will need to change before being marked as changed.
For example, if `diff_threshold` is 30, the difference between a pixels has to be equal to or more than 30 to be marked changed.
The higher this threshold, the more the pixels needs to be different to be marked.

`pixel_threshold` defines a hard cut of in the number of pixels that need to be marked as changed before outputting motion values.
This effectively sets the cutoff for noise when determining whether or not an infant is breathing.
For example, if `pixel_threshold` is set to 100, the algorithm must see more than 100 pixels of change before registering any motion as seen. It will report no motion if that threshold is not crossed.

`erode_dim` specifies the dimension of the kernel to use in an [OpenCV erode operation](http://docs.opencv.org/2.4/doc/tutorials/imgproc/erosion_dilatation/erosion_dilatation.html).
This is used to minimize the changed pixels.
That is, pixels that are isolated will be removed, but when large groups of pixels are changed, they will remain.
`dilate_dim` is the opposite, it takes a pixels and expands it.
These two parameters are used when detecting the region of the frame that the infant is located in.
First, the pixel differences are calculated, then, a small erosion is applied to eliminate noise and a large dilation is applied to broadly mark the areas of motion.

`low-cuttoff` and `high-cutoff` define the range of the bandpass filter used during magnification.
Specifically, video magnification will try to magnify motion that occurs within this frequency range, and ignore motion outside this range.
We've tuned this to be able to capture breathing rats in general, but you may need to tweak this during calibration.

See the section on calibration for more information.

## Debugging features

The `show_diff` flag in `[motion]` will show a window where the areas where motion is detected in the frame are highlighted in white.
The `show_magnification` flag in `[magnification]` controls a window that shows the output of just video magnification (which should look like the camera feed, in black and white, with enlarged motion).
You can use these two flags to show the result of your changes to the motion and magnification parameters.

Finally, the `print_times` in the `[debug]` section controls printing of frame times in the standard output, which you can use to calibrate the FPS and latency settings when running on a device different than the Raspberry Pi.

These features must be left to off when cribsense is started through systemd (automatically on boot or with `systemctl start`). They are only useful if you run cribsense manually.

## Calibrating the Motion & Magnification algorithm

Calibration of the algorithm is an iterative effort, with no right or wrong answer.
We encourage you to experiment with various values, combining them with the debugging features, to find the combination of parameters most suitable to your environment.

As a guideline, increasing the `amplification` and the `phase_threshold` values increases the amount of magnification applied to the input video.
You should change these values until you clearly see the movement from your baby breathing, and no significant artifact in other areas of the video.
If you experience artifacts, reducing the `phase_threshold` while keeping the same `amplification` might help.
You can view the effects of these parameters by setting `show_magnification` to `true`.

As for the motion detection parameters, the main driver is the amount of noise.
When detecting regions of motion to crop to, `erode_dim` and `dilate_dim` are used to size the dimensions of the OpenCV kernels used to [erode and dilate](http://docs.opencv.org/2.4/doc/tutorials/imgproc/erosion_dilatation/erosion_dilatation.html) motion so that noise is first eroded away, then the remaining motion signal is significantly dilated to make the regions of motion obvious.
These parameters may also need to be tuned if your crib is in a very high-contrast setting.
In general, you will need a higher `erode_dim` for high contrast settings, and a lower `erode_dim` for low contrast.

If you run with `show_diff = true` and you notice that too much of the input video is white, or some completely unrelated part of the video is detected as motion (e.g. a flickering lamp), you'll want to increase the `erode_dim` until only the part of the video corresponding to your breathing baby is the largest section of white.
The top figure shows an example where the erode dimension is too low for the amount of motion in the frame, while the bottom one shows a correctly calibrated frame.

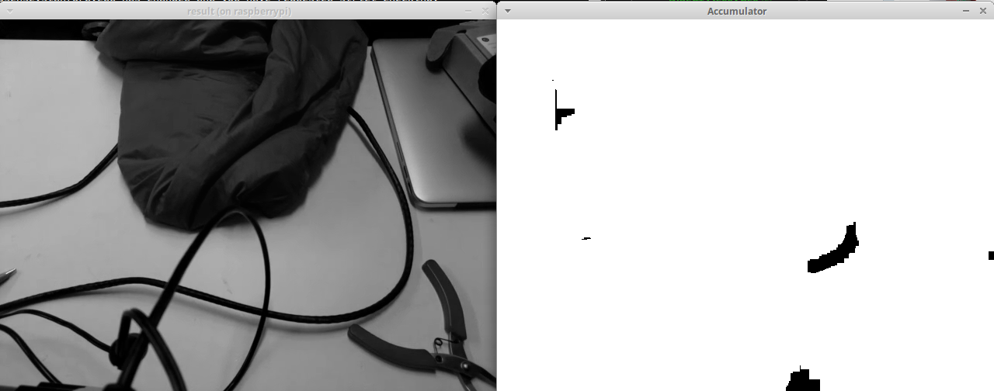
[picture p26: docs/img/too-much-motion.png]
too-much


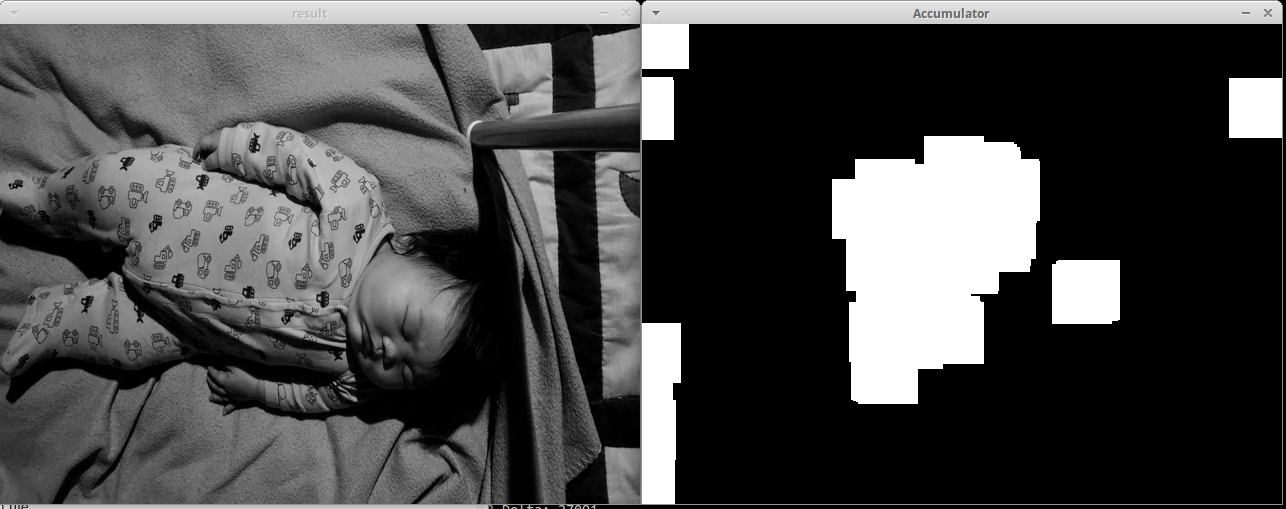
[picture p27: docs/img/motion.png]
motion


Once this has been calibrated, you'll want to make sure that the `pixel_threshold` is set so that motion is only reported when you expect, and not constantly (which means you need to cut out the noise).
Ideally, you'll see output like this in your terminal:

```sh
[info] Pixel Movement: 0	 [info] Motion Estimate: 1.219812 Hz
[info] Pixel Movement: 0	 [info] Motion Estimate: 1.219812 Hz
[info] Pixel Movement: 0	 [info] Motion Estimate: 1.219812 Hz
[info] Pixel Movement: 0	 [info] Motion Estimate: 1.219812 Hz
[info] Pixel Movement: 44	 [info] Motion Estimate: 1.219812 Hz
[info] Pixel Movement: 0	 [info] Motion Estimate: 1.219812 Hz
[info] Pixel Movement: 161	 [info] Motion Estimate: 1.219812 Hz
[info] Pixel Movement: 121	 [info] Motion Estimate: 0.841416 Hz
[info] Pixel Movement: 0	 [info] Motion Estimate: 0.841416 Hz
[info] Pixel Movement: 86	 [info] Motion Estimate: 0.841416 Hz
[info] Pixel Movement: 0	 [info] Motion Estimate: 0.841416 Hz
[info] Pixel Movement: 0	 [info] Motion Estimate: 0.841416 Hz
[info] Pixel Movement: 0	 [info] Motion Estimate: 0.841416 Hz
[info] Pixel Movement: 0	 [info] Motion Estimate: 0.841416 Hz
[info] Pixel Movement: 0	 [info] Motion Estimate: 0.841416 Hz
[info] Pixel Movement: 0	 [info] Motion Estimate: 0.841416 Hz
[info] Pixel Movement: 0	 [info] Motion Estimate: 0.841416 Hz
[info] Pixel Movement: 0	 [info] Motion Estimate: 0.841416 Hz
[info] Pixel Movement: 0	 [info] Motion Estimate: 0.841416 Hz
[info] Pixel Movement: 0	 [info] Motion Estimate: 0.841416 Hz
[info] Pixel Movement: 0	 [info] Motion Estimate: 0.841416 Hz
[info] Pixel Movement: 0	 [info] Motion Estimate: 0.841416 Hz
[info] Pixel Movement: 0	 [info] Motion Estimate: 0.841416 Hz
[info] Pixel Movement: 0	 [info] Motion Estimate: 0.841416 Hz
[info] Pixel Movement: 0	 [info] Motion Estimate: 0.841416 Hz
[info] Pixel Movement: 97	 [info] Motion Estimate: 0.841416 Hz
[info] Pixel Movement: 74	 [info] Motion Estimate: 0.839298 Hz
[info] Pixel Movement: 0	 [info] Motion Estimate: 0.839298 Hz
[info] Pixel Movement: 60	 [info] Motion Estimate: 0.839298 Hz
[info] Pixel Movement: 0	 [info] Motion Estimate: 0.839298 Hz
[info] Pixel Movement: 0	 [info] Motion Estimate: 0.839298 Hz
[info] Pixel Movement: 0	 [info] Motion Estimate: 0.839298 Hz
[info] Pixel Movement: 0	 [info] Motion Estimate: 0.839298 Hz
[info] Pixel Movement: 48	 [info] Motion Estimate: 0.839298 Hz
[info] Pixel Movement: 38	 [info] Motion Estimate: 0.839298 Hz
[info] Pixel Movement: 29	 [info] Motion Estimate: 0.839298 Hz
[info] Pixel Movement: 28	 [info] Motion Estimate: 0.839298 Hz
[info] Pixel Movement: 22	 [info] Motion Estimate: 0.839298 Hz
[info] Pixel Movement: 0	 [info] Motion Estimate: 0.839298 Hz
[info] Pixel Movement: 0	 [info] Motion Estimate: 0.839298 Hz
[info] Pixel Movement: 0	 [info] Motion Estimate: 0.839298 Hz
[info] Pixel Movement: 0	 [info] Motion Estimate: 0.839298 Hz
```
Where there is a clear periodic pattern corresponding to the motion.

If your output looks more like this:

```
[info] Pixel Movement: 921	 [info] Motion Estimate: 1.352046 Hz
[info] Pixel Movement: 736	 [info] Motion Estimate: 1.352046 Hz
[info] Pixel Movement: 666	 [info] Motion Estimate: 1.352046 Hz
[info] Pixel Movement: 663	 [info] Motion Estimate: 1.352046 Hz
[info] Pixel Movement: 1196	 [info] Motion Estimate: 1.352046 Hz
[info] Pixel Movement: 1235	 [info] Motion Estimate: 1.352046 Hz
[info] Pixel Movement: 1187	 [info] Motion Estimate: 1.456389 Hz
[info] Pixel Movement: 1115	 [info] Motion Estimate: 1.456389 Hz
[info] Pixel Movement: 959	 [info] Motion Estimate: 1.456389 Hz
[info] Pixel Movement: 744	 [info] Motion Estimate: 1.456389 Hz
[info] Pixel Movement: 611	 [info] Motion Estimate: 1.456389 Hz
[info] Pixel Movement: 468	 [info] Motion Estimate: 1.456389 Hz
[info] Pixel Movement: 371	 [info] Motion Estimate: 1.456389 Hz
[info] Pixel Movement: 307	 [info] Motion Estimate: 1.456389 Hz
[info] Pixel Movement: 270	 [info] Motion Estimate: 1.456389 Hz
[info] Pixel Movement: 234	 [info] Motion Estimate: 1.456389 Hz
[info] Pixel Movement: 197	 [info] Motion Estimate: 1.456389 Hz
[info] Pixel Movement: 179	 [info] Motion Estimate: 1.456389 Hz
[info] Pixel Movement: 164	 [info] Motion Estimate: 1.456389 Hz
[info] Pixel Movement: 239	 [info] Motion Estimate: 1.456389 Hz
[info] Pixel Movement: 733	 [info] Motion Estimate: 1.456389 Hz
[info] Pixel Movement: 686	 [info] Motion Estimate: 1.229389 Hz
[info] Pixel Movement: 667	 [info] Motion Estimate: 1.229389 Hz
[info] Pixel Movement: 607	 [info] Motion Estimate: 1.229389 Hz
[info] Pixel Movement: 544	 [info] Motion Estimate: 1.229389 Hz
[info] Pixel Movement: 499	 [info] Motion Estimate: 1.229389 Hz
[info] Pixel Movement: 434	 [info] Motion Estimate: 1.229389 Hz
[info] Pixel Movement: 396	 [info] Motion Estimate: 1.229389 Hz
[info] Pixel Movement: 375	 [info] Motion Estimate: 1.229389 Hz
[info] Pixel Movement: 389	 [info] Motion Estimate: 1.229389 Hz
[info] Pixel Movement: 305	 [info] Motion Estimate: 1.312346 Hz
[info] Pixel Movement: 269	 [info] Motion Estimate: 1.312346 Hz
[info] Pixel Movement: 1382	 [info] Motion Estimate: 1.312346 Hz
[info] Pixel Movement: 1086	 [info] Motion Estimate: 1.312346 Hz
[info] Pixel Movement: 1049	 [info] Motion Estimate: 1.312346 Hz
[info] Pixel Movement: 811	 [info] Motion Estimate: 1.312346 Hz
[info] Pixel Movement: 601	 [info] Motion Estimate: 1.312346 Hz
[info] Pixel Movement: 456	 [info] Motion Estimate: 1.312346 Hz
```
Then you'll need to adjust `pixel_threshold` and `diff_threshold` until just peaks are seen, and pixel movement is 0 otherwise.

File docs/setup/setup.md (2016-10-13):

# Setup Guide

This is the step-by-step guide on building the cribsense software on Ubuntu.

## Prerequisites
This software depends on Qt5 and OpenCV. Install these by running

```sh
sudo apt-get install qtbase5-dev qtdeclarative5-dev libqt5webkit5-dev libsqlite3-dev
sudo apt-get install qt5-default qttools5-dev-tools
```

To install [OpenCV](http://docs.opencv.org/2.4/doc/tutorials/introduction/linux_install/linux_install.html), run:
```
sudo apt-get install build-essential
sudo apt-get install cmake git libgtk2.0-dev pkg-config libavcodec-dev libavformat-dev libswscale-dev
sudo apt-get install libopencv-dev
```

## Build
To build the software, navigate to the root of the directory and run

```sh
qmake src/Magnifier.pro
make
```

To execute the program:

```
./Magnifier
```

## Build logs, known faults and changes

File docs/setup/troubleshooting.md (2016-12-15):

# Troubleshooting

Here are some troubleshooting tips we've gathered while making CribSense.

### No alarm is playing

-   Are your speakers working?
-   Can you play other sounds from the Pi outside of the CribSense alarm?
-   Is your Pi trying to play audio through HDMI rather than the audio port? Check the [Raspberry Pi Audio Configuration](https://www.raspberrypi.org/documentation/configuration/audio-config.md) page to make sure that you have selected the right output.
-   Is CribSense detecting motion? Check with `journalctl -f` to see if CribSense is running in the background. If it is, perhaps you need to [calibrate CribSense](./config.md)

### IR LED is not working

- Can you see a faint red color when you look at the IR LED? A faint red ring should be visible when the LED is on.
- Check the polarity of the connections. If +5V and GND are reversed, it will not work. 
- Connect the LED to a power supply with a 5V/0.5A voltage/current limit. Normally, it should consume 0.2A at 5V. If it does not, your LED may be malfunctioning.

### CribSense is detecting motion even though there isn't an infant

-   Have you properly [configured CribSense](./config.md)?
-   Remember, CribSense is just looking for changes in pixel values
    -   Is there a moving shadow within the frame?
    -   Is there flickering or changing lighting?
    -   Is CribSense mounted to a stable surface (e.g. something that won't shake if people are walking by it)?
    -   Is there any other sources of movement in the frame (mirrors catching reflections, etc)?

### CribSense is NOT detecting motion even though there is motion

-   Have you properly [configured CribSense](./config.md)?
-   Is there anything in the way of the camera?
-   Are you able to connect to the camera from the Raspberry Pi at all? Check by running `raspistill -v` in a terminal to open the camera on the Pi for a few seconds.
-   If you look at `sudo systemctl status cribsense`, is it actually running?
-   Is your infant under a blanket that is "tented" up so that it is not making contact with the child? If there are significant air gaps between the blanket and the child, the blanket may mask the motion.
-   Can you see the motion if you amplify the video more?
-   Can you see the motion if you tune the low and high frequency cutoffs?
-   If this is happening in low-light only, did you make sure your calibration works in low-light?

### CribSense doesn't build

-   Did you [install all of the dependencies](./sw-setup.md)?

### I can't run `cribsense` from the commandline

-   Did you accidentally mistype anything when you ran `./autogen.sh --prefix=/usr --sysconfdir=/etc --disable-debug` during your software build?
-   Is `cribsense` present in `/usr/bin/`?

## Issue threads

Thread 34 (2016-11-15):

Document circuitry needed to hook the IR LED to the Pi.

lukehsiao, 2016-11-15:
We'll want to know what parts were used and how they are hooked up, plus some pictures. Whatever information is necessary for a non-technical person to reproduce it from the instructable.

lukehsiao, 2016-12-06:
Added to the docs.

Closed 2016-12-06.

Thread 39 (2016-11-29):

Add source files & documentation for 3D printing chassis to repo

lukehsiao, 2016-11-29:
We can add a `chassis/` folder to the root and have the model files there. Ideally, people can just come to this repo for all the files needed to recreate the project.

lukehsiao, 2016-12-09:
Also need to add any new render images to `docs/img/` and fill out the documentation on both GitHub and Instructable on the print process/design decisions and assembly. I'll work on some of the assembly instructions.

lukehsiao, 2016-12-11:
closed in fe477f14f3a42ecf77f10743f504c29f35c59572

Closed 2016-12-11.

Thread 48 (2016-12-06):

Resolder photodiode to the rear of the LED

lukehsiao, 2016-12-06:
Pan, can you desolder and photodiode that is on the front of the IR LED and solder it to the back?

lukehsiao, 2016-12-08:
Thanks @lghupan ! Closing this issue.

Closed 2016-12-08.

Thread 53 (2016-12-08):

Feedback for documentation/instructable

lukehsiao, 2016-12-08:
Here's the feedback we got.

From Phil:

- [x] adding a bit more detail on how things work and why. E.g., explain what each of the three libraries use and why you chose them (well, maybe not autoconf).
- [x] Please include a troubleshooting section: if X doesn’t work, what should someone look at? Is there a consistent problem you run into? Think not just about telling someone how to do it if everything goes perfectly, but also how to recover from failures.
- [x] Please explain what it’s actually doing and include a video of it operating. (#49)
- [x] You’re in some ways suggesting a safety device, and so need to explain its limitations/issues. You don’t want someone to actually use this to protect their baby then come after you when it fails. I.e., say that you embarked on this to figure out whether it was possible, and a real product would need more QA, etc.
- [x] Show what a full setup looks like. How do you install the camera? What considerations are there for its placement/orientation? Should they worry about HDR/light?

From Shane:

- [x] A picture of the camera cable replacement process would be helpful
- [x] Not strictly necessary, but it would be good to communicate that the chassis itself is an 'optional' part of the build if they have other means of constructing it. Separating the materials list into "chassis-related" and "electronics/essential" would be helpful in that regard
- [x] Providing a simple 'hello world' version of the configuration file (inline if possible) would help people immediately understand the syntax and the relevant parameters without the need to read every word of your Software Configuration document.
- [x] Alongside your (really cool) picture of the CAD model, it would be great to see a picture of the finished build on the first page. This will give your project a much more tangible and 'do-able' feel. When people see a CAD model, they think 'fancy', but when they see a picture of a real project, right away they can better envision themselves using or building it.
- [x] Step 4 was a great example of explaining design decisions with technical detail. It would be good to have a little bit more of a technical overview of the software design in this fashion.
- [x] With your software license, good job listing the relevant dependency licenses in your README, but don't forget to explicitly license the CribSense code that you guys wrote as well.
- [x] Finally, make sure you have a summary or step that focuses on the nominal usage, eg. once they've done all the necessary setup and calibration.

lukehsiao, 2016-12-08:
I'm checking these things off as I add them to the github repo docs. Once everything is in the GitHub repo, we can uncheck them as we make sure they're in the instructable.

lukehsiao, 2016-12-09:
Ok, I think I've gotten basically all of these points in both our GitHub docs and the Instructable. The only holes remaining are the Chassis docs. If you all could take a look and do some editing, that would be great.

lukehsiao, 2016-12-11:
William has added the chassis info. All that is needed now is a final sync between github docs and the instructable.

lukehsiao, 2016-12-14:
Shane wants us to make a **Troubleshooting** step to the instructable.

Closed 2016-12-15.

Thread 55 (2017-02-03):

Virtual Camera Source

dtynski, 2017-02-03:
I'm running a virtual camera source instead of the camera in your tutorial.  When I specify that camera (which I can view via VLC so I know the virtual device is working), I get a "invalid argument error from Cribsense. Any idea how to troubleshoot?

gcampax, 2017-02-03:
Try running it in strace (strace -e trace=ioctl cribsense) to see what IOCTL is failing. It's likely that we're passing some parameter value (eg picture format) that is valid for the Pi driver but not for your camera.

Closed 2017-03-14.

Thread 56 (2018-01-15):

Viewing the video stream

tomforsyth90, 2018-01-15:
This is exactly what I was looking to implement into my baby monitor. I've got it working so it is currently streaming the video via gstreamer but wanted to know if there was a way to use this also to monitor movement and breathing? If I download CribSense on a new sd card it runs fine but if I run it on the sd card i'm using for my baby monitor video stream it doesn't work and fails after starting the batch processing.. any suggestions how I can get this to work? Also is there a way to visualise the pixel movement and motion estimate to reflect breathing rate? Thanks

lukehsiao, 2018-01-15:
>If I download CribSense on a new sd card it runs fine but if I run it on the sd card i'm using for my baby monitor video stream it doesn't work and fails after starting the batch processing.. any suggestions how I can get this to work?

This one would be hard to debug without a lot of details. I'm not sure what might be causing this.

>Also is there a way to visualise the pixel movement and motion estimate to reflect breathing rate?

It is possible to show the diff frames similar to the one you see during configuration
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

but in our implementation, rendering these added too much overhead and the Pi couldn't keep up. Adding any other visual indicators would have to be very lightweight. We do have some estimates of the motion that we can output to the terminal as shown [on the configuration page](https://lukehsiao.github.io/CribSense/setup/config/), if that's helpful. I've copied it here for convenience:

```
[info] Pixel Movement: 0     [info] Motion Estimate: 1.219812 Hz
[info] Pixel Movement: 0     [info] Motion Estimate: 1.219812 Hz
[info] Pixel Movement: 0     [info] Motion Estimate: 1.219812 Hz
[info] Pixel Movement: 0     [info] Motion Estimate: 1.219812 Hz
[info] Pixel Movement: 44    [info] Motion Estimate: 1.219812 Hz
[info] Pixel Movement: 0     [info] Motion Estimate: 1.219812 Hz
[info] Pixel Movement: 161   [info] Motion Estimate: 1.219812 Hz
[info] Pixel Movement: 121   [info] Motion Estimate: 0.841416 Hz
[info] Pixel Movement: 0     [info] Motion Estimate: 0.841416 Hz
[info] Pixel Movement: 86    [info] Motion Estimate: 0.841416 Hz
[info] Pixel Movement: 0     [info] Motion Estimate: 0.841416 Hz
[info] Pixel Movement: 0     [info] Motion Estimate: 0.841416 Hz
[info] Pixel Movement: 0     [info] Motion Estimate: 0.841416 Hz
[info] Pixel Movement: 0     [info] Motion Estimate: 0.841416 Hz
[info] Pixel Movement: 0     [info] Motion Estimate: 0.841416 Hz
[info] Pixel Movement: 0     [info] Motion Estimate: 0.841416 Hz
[info] Pixel Movement: 0     [info] Motion Estimate: 0.841416 Hz
[info] Pixel Movement: 0     [info] Motion Estimate: 0.841416 Hz
[info] Pixel Movement: 0     [info] Motion Estimate: 0.841416 Hz
[info] Pixel Movement: 0     [info] Motion Estimate: 0.841416 Hz
[info] Pixel Movement: 0     [info] Motion Estimate: 0.841416 Hz
[info] Pixel Movement: 0     [info] Motion Estimate: 0.841416 Hz
[info] Pixel Movement: 0     [info] Motion Estimate: 0.841416 Hz
[info] Pixel Movement: 0     [info] Motion Estimate: 0.841416 Hz
[info] Pixel Movement: 0     [info] Motion Estimate: 0.841416 Hz
[info] Pixel Movement: 97    [info] Motion Estimate: 0.841416 Hz
[info] Pixel Movement: 74    [info] Motion Estimate: 0.839298 Hz
[info] Pixel Movement: 0     [info] Motion Estimate: 0.839298 Hz
[info] Pixel Movement: 60    [info] Motion Estimate: 0.839298 Hz
[info] Pixel Movement: 0     [info] Motion Estimate: 0.839298 Hz
[info] Pixel Movement: 0     [info] Motion Estimate: 0.839298 Hz
[info] Pixel Movement: 0     [info] Motion Estimate: 0.839298 Hz
[info] Pixel Movement: 0     [info] Motion Estimate: 0.839298 Hz
[info] Pixel Movement: 48    [info] Motion Estimate: 0.839298 Hz
[info] Pixel Movement: 38    [info] Motion Estimate: 0.839298 Hz
[info] Pixel Movement: 29    [info] Motion Estimate: 0.839298 Hz
[info] Pixel Movement: 28    [info] Motion Estimate: 0.839298 Hz
[info] Pixel Movement: 22    [info] Motion Estimate: 0.839298 Hz
[info] Pixel Movement: 0     [info] Motion Estimate: 0.839298 Hz
[info] Pixel Movement: 0     [info] Motion Estimate: 0.839298 Hz
[info] Pixel Movement: 0     [info] Motion Estimate: 0.839298 Hz
[info] Pixel Movement: 0     [info] Motion Estimate: 0.839298 Hz
```

We have no plans on adding any other visualizations at this time, but pull requests are always welcome.

tomforsyth90, 2018-01-18:
Ah okay, well is it possible for the rpi camera to be used for two tasks simultaneously? I assume that might be the issue? Is it possible to change your sound alerts when no motion is found to instead of setting off the speaker to send a push notification etc? I was planning on not using a speaker but if motion wasn't detected it would alert my mobile phone instead...

lukehsiao, 2018-01-19:
>Ah okay, well is it possible for the rpi camera to be used for two tasks simultaneously?

This one I'm not sure about. We are _heavily_ utilizing the resources on the Pi, so I suspect trying to do any other computationally heavy task on the Pi will not work out well.

>Is it possible to change your sound alerts when no motion is found to instead of setting off the speaker to send a push notification etc? I was planning on not using a speaker but if motion wasn't detected it would alert my mobile phone instead...

You should be able to implement that, yes. We just have a simple [placeholder function here](https://github.com/lukehsiao/CribSense/blob/2674eec474acb4576536e4058db2e93405e903da/src/MotionDetection.cpp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) that plays the sound. You could definitely implement a push notification instead.

gcampax, 2018-01-19:
You cannot open the same video device from two processes at the same time, so you cannot have two processes streaming from the camera.
You could copy the data around, but keep in mind at the current resolution even just a copy can have noticeable performance impact.

tomforsyth90, 2018-01-19:
@gcampax what about using something like v4l2loopback which "allows you to create "virtual video devices" normal (v4l2) applications will read these devices as if they were ordinary video devices, but the video will not be read from e.g. a capture card but instead it is generated by another application. this allows you for instance to apply apply some nifty video effects on your Skype video... it also allows some more serious things" Would using this make it possible?

gcampax, 2018-01-19:
I'm not familiar with v4l2loopback, but from the description it appears it would work.
At the same time, again you might want to consider the overhead of copying the data around, or whether v4l2loopback and the process actually reading from the camera can support zero-copy sharing using dma-bufs. Assuming the raspberry pi camera driver supports dma-buf, which might depend on the kernel version.
Another all-in-one solution for multiple process access to the camera is https://github.com/PipeWire/pipewire (formerly pithos formerly pulsevideo), but again that depends on dma-buf and might have overhead. At the same time, dma-buf will give you zero-copy sharing with the output graphic card as well, so you might get pass through video overlay with small overhead, assuming you insist hard enough in your userspace.

tomforsyth90, 2018-01-20:
Right okay thanks for the link and insight.. What about using a webcam instead of the rpi camera? Next question ha.. the estimates of motion you see in the command terminal, how would I go about embedding that into a webpage so you could view the real time detected motion or is that not possible and I should just let it run in the back ground?

tomforsyth90, 2018-01-22:
@gcampax thanks for getting back to me. I've had a look at v4l2loopback but it says i need to have specific kernel headers installed but doesn't explain how to ensure you have the right ones installed and the pipewire alternative i cant figure out how to install without sudo-apt get lol :( could you walk me through it please otherwise i'm going to have to buy a second pi and camera and run cribsense completely separately which would be annoying.

gcampax, 2018-01-22:
I'm afraid I can't help you, I am not familiar with these projects, I just know they exist.
At least pipewire should be installable from sources using a standard build system, as described in their README.

tomforsyth90, 2018-01-22:
That's okay, thanks. Do you think Cribsense will be able to run on a raspberry pi zero? Think i'm going to have to run it on a separate pi now to be honest.

lukehsiao, 2018-01-26:
Right now, yes. It's setup to turn on, look for motion, and then begin monitoring. If there is no baby and no motion, then the alarm would sound.

tomforsyth90, 2018-01-28:
That's okay i'll ensure that is the case in my project then, cheers

Closed 2018-01-15.

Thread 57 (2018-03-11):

Question

tomforsyth90, 2018-03-11:
Hi

Just wondering how I can change the code so I can play an mp3 file when the system alarms?
Also, I'm wondering if could tell me how I could make a specific gpio pin go high when the alarm is triggered and stay low/ return to low the rest of the time?

Cheers guys, will really appreciate it

lukehsiao, 2018-03-12:
We play the alarm in [this file](https://github.com/lukehsiao/CribSense/blob/b67ae6a18a34dfdd900ef8728e4309a9aa780e81/src/MotionDetection.cpp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).

You can modify that however you would like to play different sounds, or control [GPIO pins](https://www.raspberrypi.org/documentation/usage/gpio-plus-and-raspi2/README.md). We don't actually use any GPIO in this project, besides as a power source for the LED. So, I'd recommend checking out other online tutorials for how to set up GPIO using C++ on the Raspberry Pi.

tomforsyth90, 2018-03-12:
Sorry I'm not very experienced with C. What exactly in that file would need changing to make it play an mp3 file?
Thanks

On 12 Mar 2018 05:49, Luke Hsiao <notifications@github.com> wrote:

We play the alarm in this file<https://github.com/lukehsiao/CribSense/blob/b67ae6a18a34dfdd900ef8728e4309a9aa780e81/src/MotionDetection.cpp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>.

You can modify that however you would like to play different sounds, or control GPIO pins<https://www.raspberrypi.org/documentation/usage/gpio-plus-and-raspi2/README.md>. We don't actually use any GPIO in this project, besides as a power source for the LED. So, I'd recommend checking out other online tutorials for how to set up GPIO using C++ on the Raspberry Pi.

—
You are receiving this because you authored the thread.
Reply to this email directly, view it on GitHub<https://github.com/lukehsiao/CribSense/issues/57#issuecomment-372200313>, or mute the thread<https://github.com/notifications/unsubscribe-auth/AhC5JqNma9BuTPjm3ujEg3Yp76vMZYaOks5tdgx6gaJpZM4Slvml>.

tomforsyth90, 2018-03-19:
@lukehsiao Hi Luke, I can't get the alarm to work, my speakers are working fine as I can play other stuff through them via the Pi.. any ideas what I can do? Or how I can change the current alarm to something else? Thanks!

lukehsiao, 2018-03-19:
I'd check out the other troubleshooting tips first: https://lukehsiao.github.io/CribSense/setup/troubleshooting/

tomforsyth90, 2018-03-19:
Gone through all of that.. its definitely using the audio jack but not playing an alarm when i run` cribsense --config /etc/cribsense/config.ini`

lukehsiao, 2018-03-19:
Is it detecting motion? Have you calibrated?

tomforsyth90, 2018-03-20:
It detects motion and when no motion is detected during testing it prints error no motion is detected and then resets after a little while and runs through it all again... it's just not alarming.. i've tried changing the printf file to see if its updating changes but that won't print anything other than the original 'error no motion is detected' text

lukehsiao, 2018-03-20:
Have you installed all dependencies (e.g. libcanberra-dev)?

tomforsyth90, 2018-03-20:
yeah just double checked and they're all installed and updated

tomforsyth90, 2018-04-14:
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

This is what happens when i enable cribesense and did the journal to check if its running.. not sure if its actually enabling properly?

Still can't get the alarm to sound, but even if i change the text in this section it still prints the original error no movement detected message.... any ideas?

Thanks

Tom

tomforsyth90, 2018-04-18:
Do I need to change anything in any other file to allow editing to occur?

lukehsiao, 2018-04-19:
Are you [rebuilding the project](https://lukehsiao.github.io/CribSense/setup/sw-setup/#build) after your edits?

tomforsyth90, 2018-04-19:
No.. do i need to rerun this code again after each edit then?
`./autogen.sh --prefix=/usr --sysconfdir=/etc --disable-debug
make
sudo make install
sudo systemctl daemon-reload`

lukehsiao, 2018-04-19:
I believe you can just
```
$ make
$ sudo make install
$ sudo systemctl daemon-reload
```
Give that a shot. Right now you've edited the code, but are just running the old executables.

tomforsyth90, 2018-04-19:
LOL i've spent weeks trying to make changes to that file and all i needed to do what that!! Thankyou!!!! Undoubtedly I will have another question for you when i get stuck again... thanks though Luke!!

tomforsyth90, 2018-04-19:
I still cant get the alarm to play through the speakers, but I can play other mp3 files through them so not sure why its not doing it. What would I need to replace within this code to get it play an mp3 file: home/pi/music/alarm.mp3 and play that until motion is detected again and how should it be written?
`void MotionDetection::soundAlarm() {
    int playing;

    ca_context_playing(snd_context, 0, &playing);
    if (playing == 0)
        ca_context_play(snd_context, 0, CA_PROP_EVENT_ID, "alarm-clock-elapsed", nullptr);
    printf("[ERROR] >>>>> NO MOVEMENT DETECTED!!!!!!\n\n");`

cheers Luke :)

tomforsyth90, 2018-04-21:
I've put printf('test'); before int playing; and after it and that gets displayed in the command terminal so its obviously calling the script properly... does there need to be some sort of audio file that the alarm plays? how or what is it using to play an alarm at the moment?

tomforsyth90, 2018-04-22:
Just to let you know that I have found a work around which can be used if anyone else is have issue with the alarm playing.. add the following

#include <stdlib.h>

and replace soundAlarm() with:

void MotionDetection::soundAlarm() {
printf("[ERROR] >>>>> NO MOVEMENT DETECTED!!!!!!\n\n");
system("omxplayer /home/pi/Music/AnySoundOrSongYouWish.mp3");

:)

lukehsiao, 2018-04-22:
We use `libcanberra` to play the alarm. I'm not sure exactly what the issue you had was, but it appears that libcanberra wasn't able to find the `alarm-clock-elapsed` audio. Your workaround is one way to do it (calling an external program), but you can also look for other libraries that can play mp3 directly in C++.

Closed 2018-03-12.

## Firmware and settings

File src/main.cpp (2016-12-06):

#include <fstream>
#include <inttypes.h>

#include "VideoSource.hpp"
#include "MotionDetection.hpp"

#include <time.h>

static inline void print_time(uint64_t& time, char c) {
	struct timespec ts;
    clock_gettime(CLOCK_MONOTONIC, &ts);

    uint64_t new_time = (uint64_t)((uint64_t)ts.tv_sec * 1000000 + (uint64_t)ts.tv_nsec / 1000);

    if (time == 0) {
        fprintf(stderr, "%c Start time: %" PRIu64 "\n", c, new_time);
        time = new_time;
    } else {
	fprintf(stderr, "%c Delta: %" PRIu64 "\n", c, new_time - time);
	time = new_time;
    }
}

// Transform video in command-line or "batch" mode according to cl.
// Return 0 on success or 1 on failure.
//
static int batch(const CommandLine &cl)
{
    // Buffer of 3 frames for use with the DifferentialCollins algorithm.
    MotionDetection detector(cl);

    uint64_t frame_time = 0;
    VideoSource source(cl.cameraId, cl.inFile, cl.input_fps, cl.frameWidth, cl.frameHeight);
    if (cl.showTimes)
        print_time(frame_time, 'A');
    for (;;) {
        // for each frame
        cv::Mat frame; const bool more = source.read(frame);
        if (cl.showTimes)
            print_time(frame_time, 'A');
        if (frame.empty()) {
            if (cl.showTimes)
                print_time(frame_time, 'B');
            if (!more) {
                //time(&end);
                //double diff_t = difftime(end, start);
                //printf("[info] time: %f\n", diff_t);
                return 0;
            }
        } else {
            detector.update(frame);
            if (cl.showTimes)
                print_time(frame_time, 'B');
        }
    }
}

int main(int argc, char *argv[])
{
    try {
        const CommandLine cl(argc, argv);
        if (cl.help || cl.about) return 0;
        if (cl.ok) {
            printf("[info] starting batch processing.\n");
            if (cl.sourceCount) return batch(cl);
        }
    } catch (const std::runtime_error& e) {
        // die gracefully for uncaught runtime errors
        std::cerr << "System error: " << e.what() << std::endl;
    }
    return 1;
}

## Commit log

2016-10-22 Multi thread (#13)
    * add thread flags to .pro
    * two threads
    * add threads to commandline processing
    * restore static
    * restore static to minimumfps const
    * reword comment
2016-10-26 Use a long running worker threads instead of std::async
    std::async spawns a new thread for every call, which is wasteful.
    Instead, use a fixed size thread pool and push new items using a queue.
    For practicality, the queue is just std::queue + std::mutex, instead
    of something fancy like a lock-free queue or RCU. It is unlikely
    there will be contention so it does not matter.
    [main.cpp]
2016-10-27 adaptive crop implementation (#14)
    closes #11. Crops an input video based on a hard-coded color, currently tuned for `lowres_5fps_yellow.h264`.
2016-11-01 Fix compiler flags for arm
2016-11-03 Put frame size in the config file
2016-11-08 Remove GUI. Implement motion-based cropping. (#24)
    Cut out all of the GUI parameters and the GUI code.
    We also implement a software state machine in
    MotionDetection so that the video can be monitored
    and cropped at regular intervals.
2016-11-10 VideoSource: add a giant HACK to set the camera fps
    We need to go low level and talk to v4l2 to set the fps, because
    opencv is dumb. And the way to do so is to walk all fds and bang
    them until we find the right one...
2016-11-10 Frame timings
2016-11-17 Use V4L2 API directly and bypass dumb OpenCV (#36)
    * main: fix format type warnings
    The exact format string depends on the architecture we're running on,
    because C.
    * main: catch runtime errors and die gracefully
    Uncaught exceptions cause an abort(), which leaves a coredump around
    and is not nice. runtime errors are usually misconfiguration, and
    there is little we can do about them, just catch them and leave
    an error message.
    * VideoSource: rewrite to use the V4L2 API directly
    As it turns out, V4L2 is actually fairly easy to use as an API,
    we can just hand code the few (quite a few, actually) ioctls we
    need and move from there.
    This as two main advantages:
    1) We cont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
    [main.cpp]
2016-11-29 Adds a rough breathing rate estimate and sounds alarm after no movement (#35)
    closes #28. Adds rough estimate of breating rate that is smoothed using an EWMA. This can be refined later, but this commit sets up the framework.
2016-11-29 VideoSource: switch to native YUV/YCbCr
    All our operations are in the Y channel (grayscale), so we don't
    even need to read Cb/Cr from device memory, let alone spend precious
    cycles converting to rgb (in hw), then to ycbcr (in sw),
    then to rgb again (in sw) then to y again (in sw).
    The tricky part is that YUV is a planar format, not a packed format.
    That means that you get the Y component of all pixels, followed by
    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
2016-11-29 VideoSource: revert back to the non-planar API
    The raspberrypi driver does not export the capability bit for the
    planar API, so the v4l2 core code just rejects any planar call
    (even though the driver supports planar formats).
    [config.ini]
2016-11-29 MotionDetection: fix frame buffer
2016-12-01 Add full frame and cropped frame FPS values. (#43)
    Closes #30. The configuration file now has 3 fps parameters. All 3 are used when reading from the camera, and only `input_fps` is used when reading from a file. This also removes Travis-CI.
2016-12-06 build: switch to autotools
    We don't use Qt anymore, and we should not even link to it.
2016-12-06 Add a command line option not to print frame times
    They are only useful for debugging
2016-12-07 Add Pan's LED schematic
2016-12-07 Update waffle badge now that we switched to open-source.
2016-12-07 Add Pan's description of the LED circuit.
    This closes #34.
2016-12-07 Fix typo and switch to 12" flex cable.
2016-12-07 Add pictures of IR LED circuit to docs.
2016-12-08 Add additional images of assembly.
2016-12-08 add example calibration pics and rename render
2016-12-08 Add the driver instruction to docs.
    Closes #51.
2016-12-08 Add checks for commandline for camera fps.
2016-12-08 adjust default camera fps to 15
2016-12-08 Separate materials list.
    Also adds the autogenerated lt-tool files to
    the autogenerated .gitignore.
2016-12-08 Add limitations and sample config to docs.
2016-12-09 Add pic/instructions of replacing camera cable.
2016-12-09 Update index pictures. Fix a couple typos.
2016-12-09 Embed videos to index.md. Minor text fixes.
    [config.ini]
2016-12-09 add assembly instructions
2016-12-10 Added updated renderings and print orientation renderings
2016-12-10 Added 3D files to /chassis
    [CribSense Cover.STL, CribSense.STL]
2016-12-11 change chassis file names
    [case.stl, cover.stl]
2016-12-11 added chassis build instructions, also edited the hardware setup document
2016-12-11 Switch to direct links to makerbot files.
2016-12-14 switch sw-setup to multiline paragraphs for diffs.
2016-12-15 updated trouble shooting for IR LED
2017-03-17 Fix two broken links in hw-setup.md
    Google Webmaster Tools showed broken links for the case and
    cover STL files. These URLS have now been replaced with
    links to the files on GitHub.
